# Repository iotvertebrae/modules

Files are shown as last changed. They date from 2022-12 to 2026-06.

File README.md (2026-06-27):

# IoT Vertebrae 

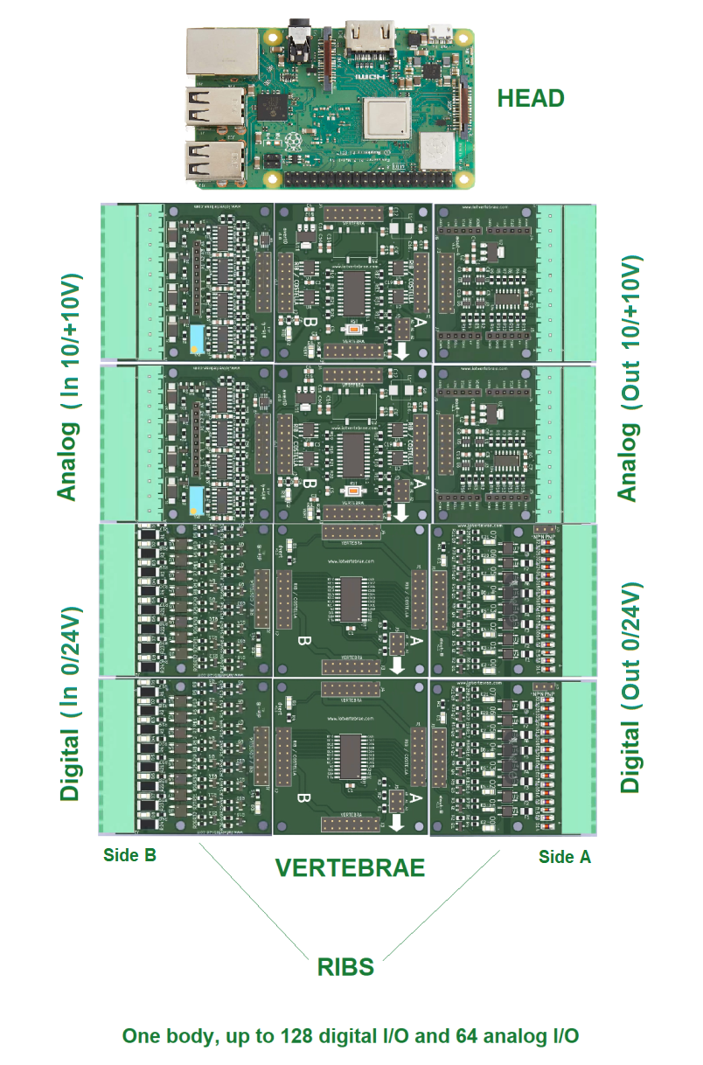
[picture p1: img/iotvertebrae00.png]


The vertebrae bus is an extenxion of the [UEXT](https://www.olimex.com/Products/Modules/UEXT) open bus proposed by Olimex.

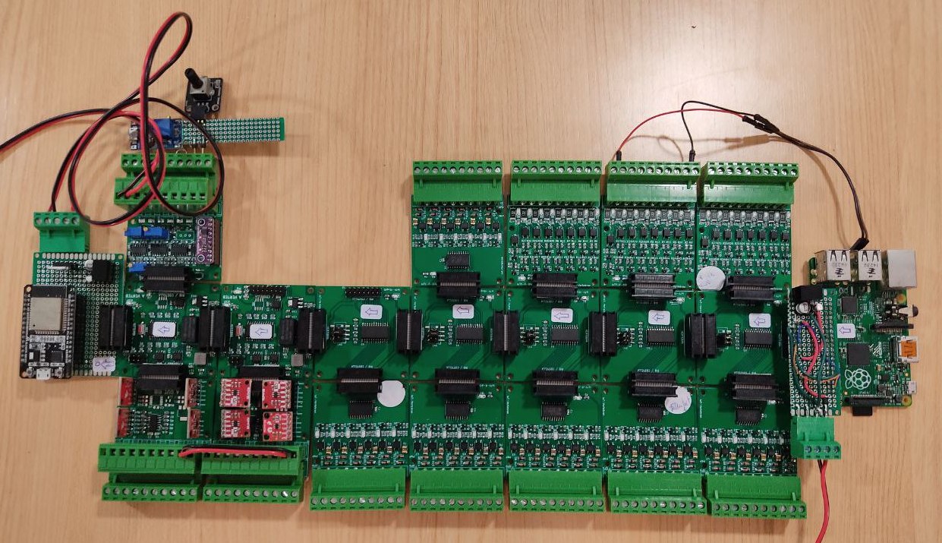
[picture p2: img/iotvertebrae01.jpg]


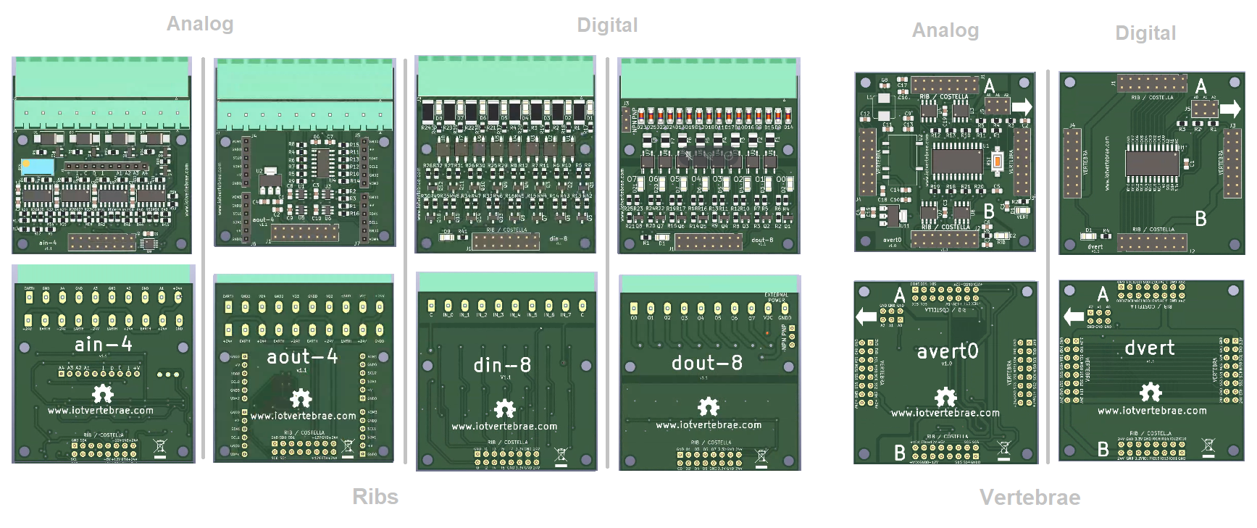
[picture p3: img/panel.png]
Modules


Modules

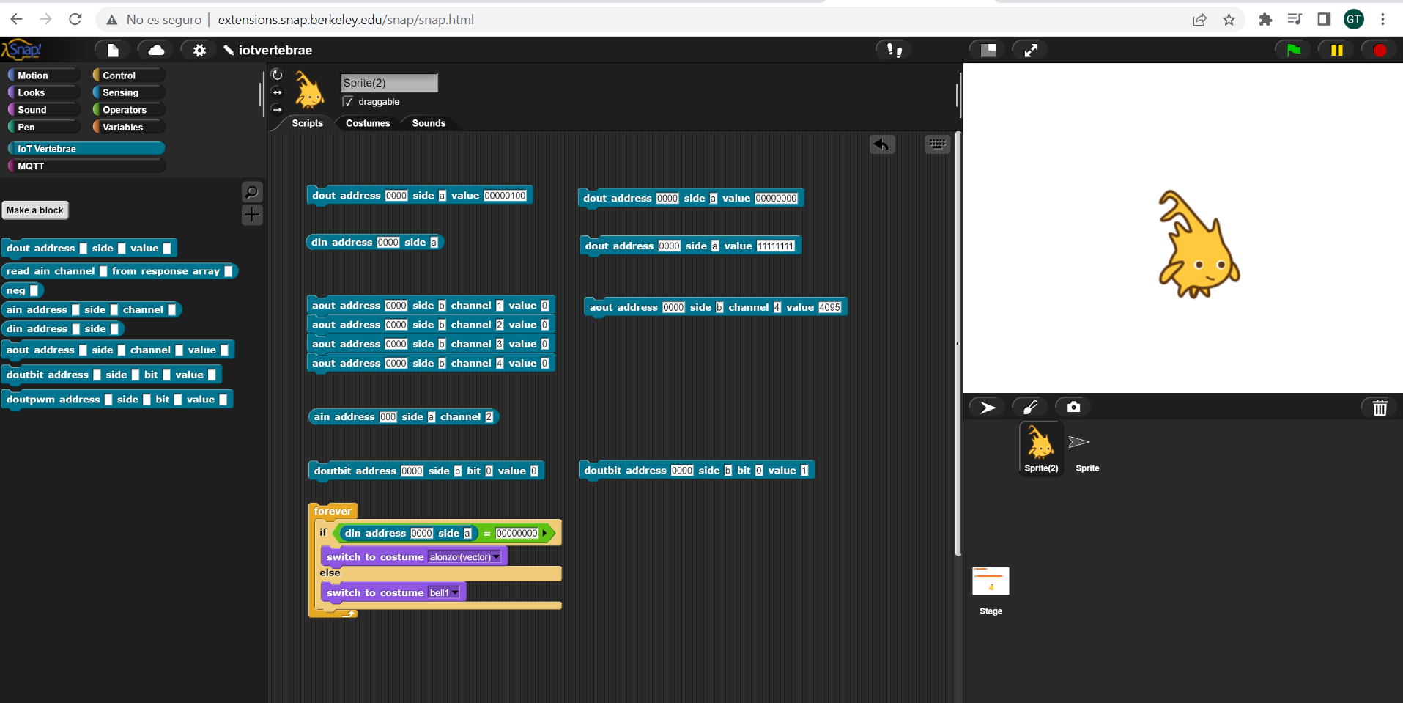
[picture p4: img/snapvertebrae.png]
Software


This project will be provided as open-source hardware.

## [Using IoT Vertebrae (Wiki)](https://www-binefa-com.translate.goog/index.php/IoT-Vertebrae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)

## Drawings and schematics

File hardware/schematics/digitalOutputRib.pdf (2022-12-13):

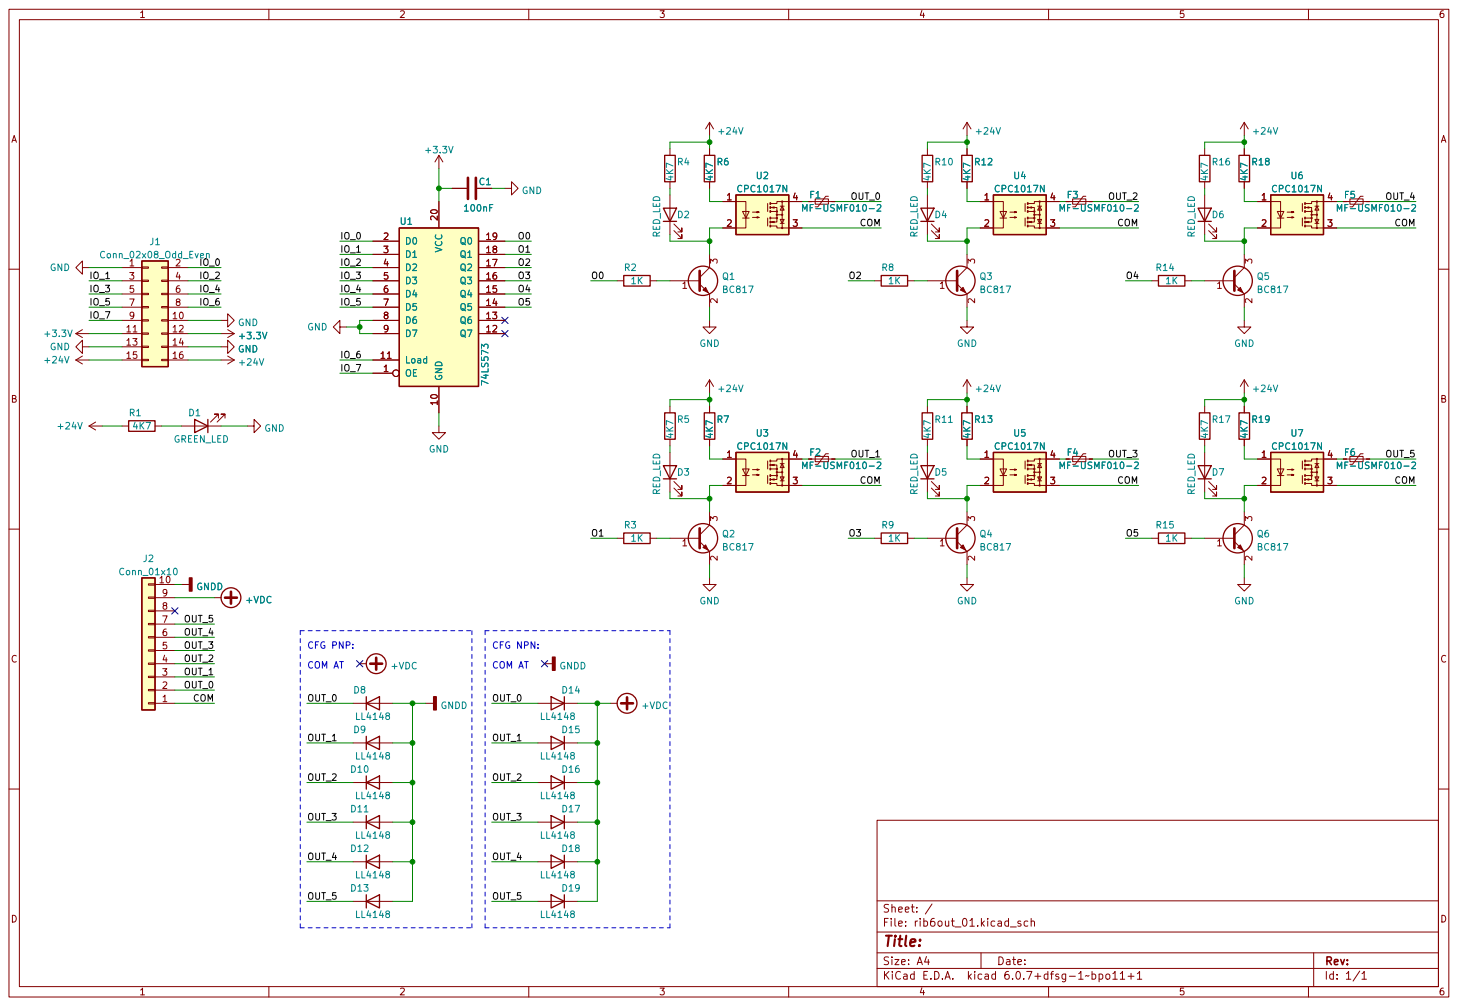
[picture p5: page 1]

2 3 Q6BC817 GND GND GND GND

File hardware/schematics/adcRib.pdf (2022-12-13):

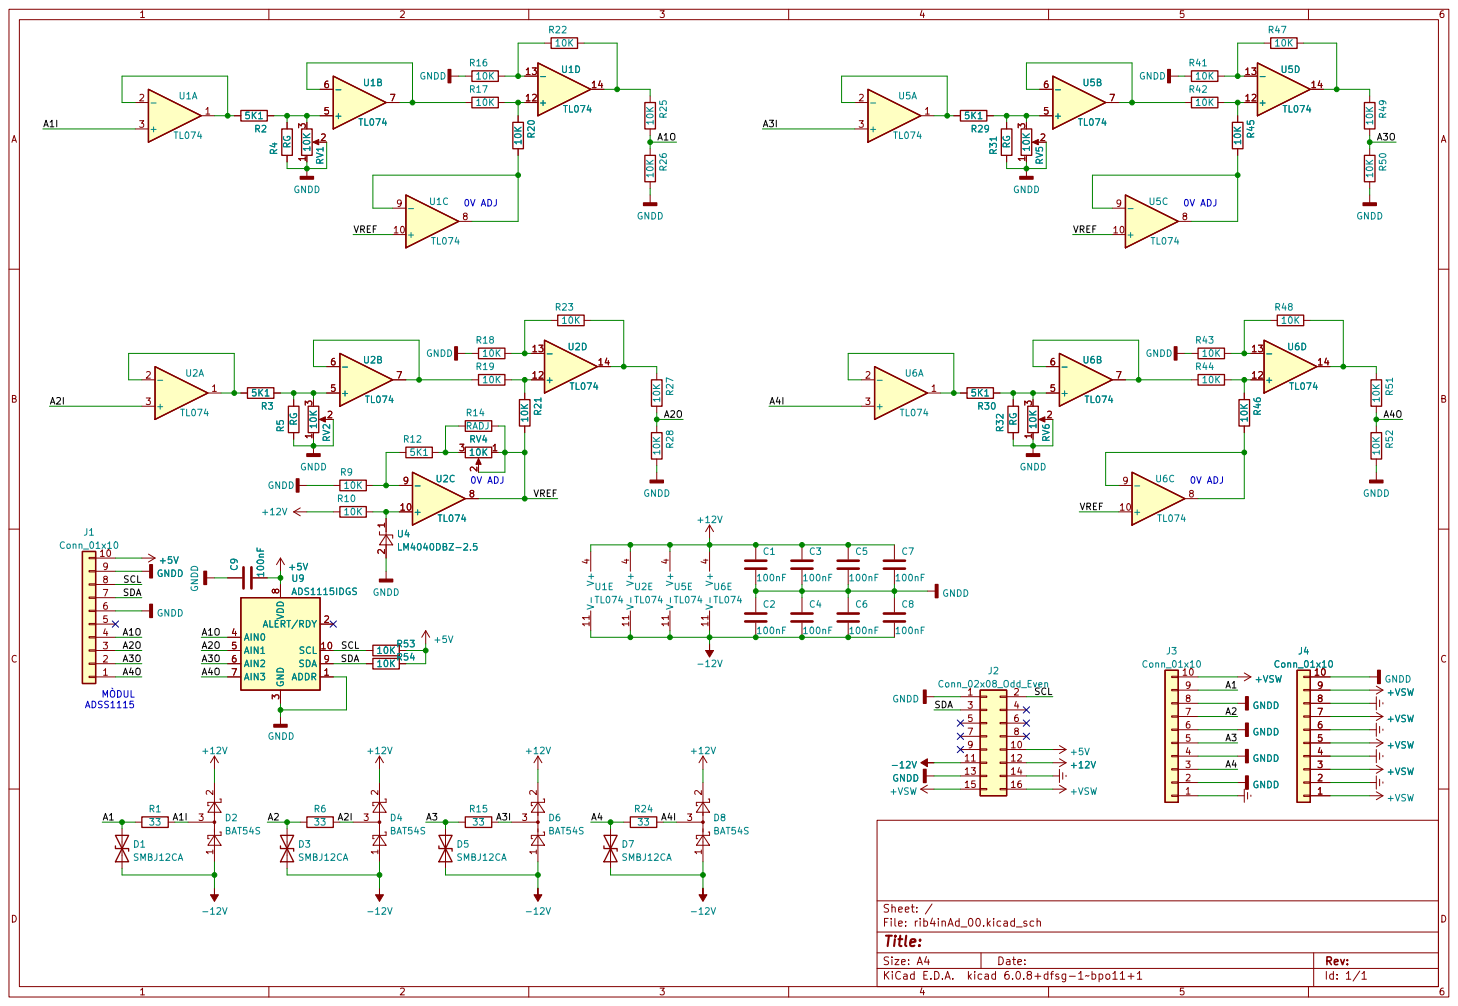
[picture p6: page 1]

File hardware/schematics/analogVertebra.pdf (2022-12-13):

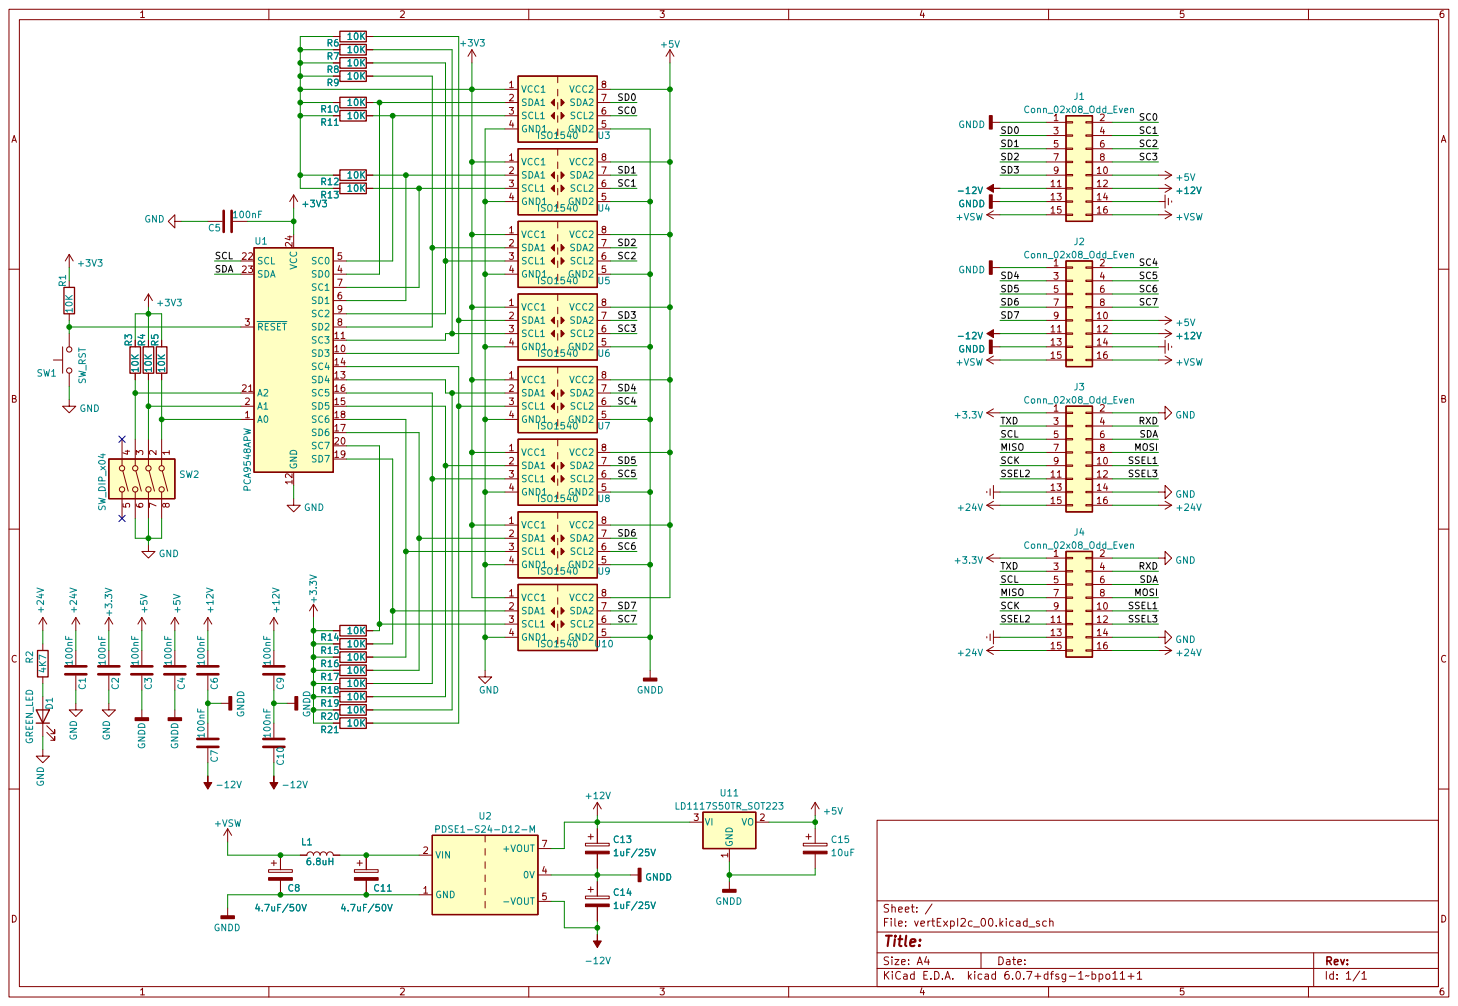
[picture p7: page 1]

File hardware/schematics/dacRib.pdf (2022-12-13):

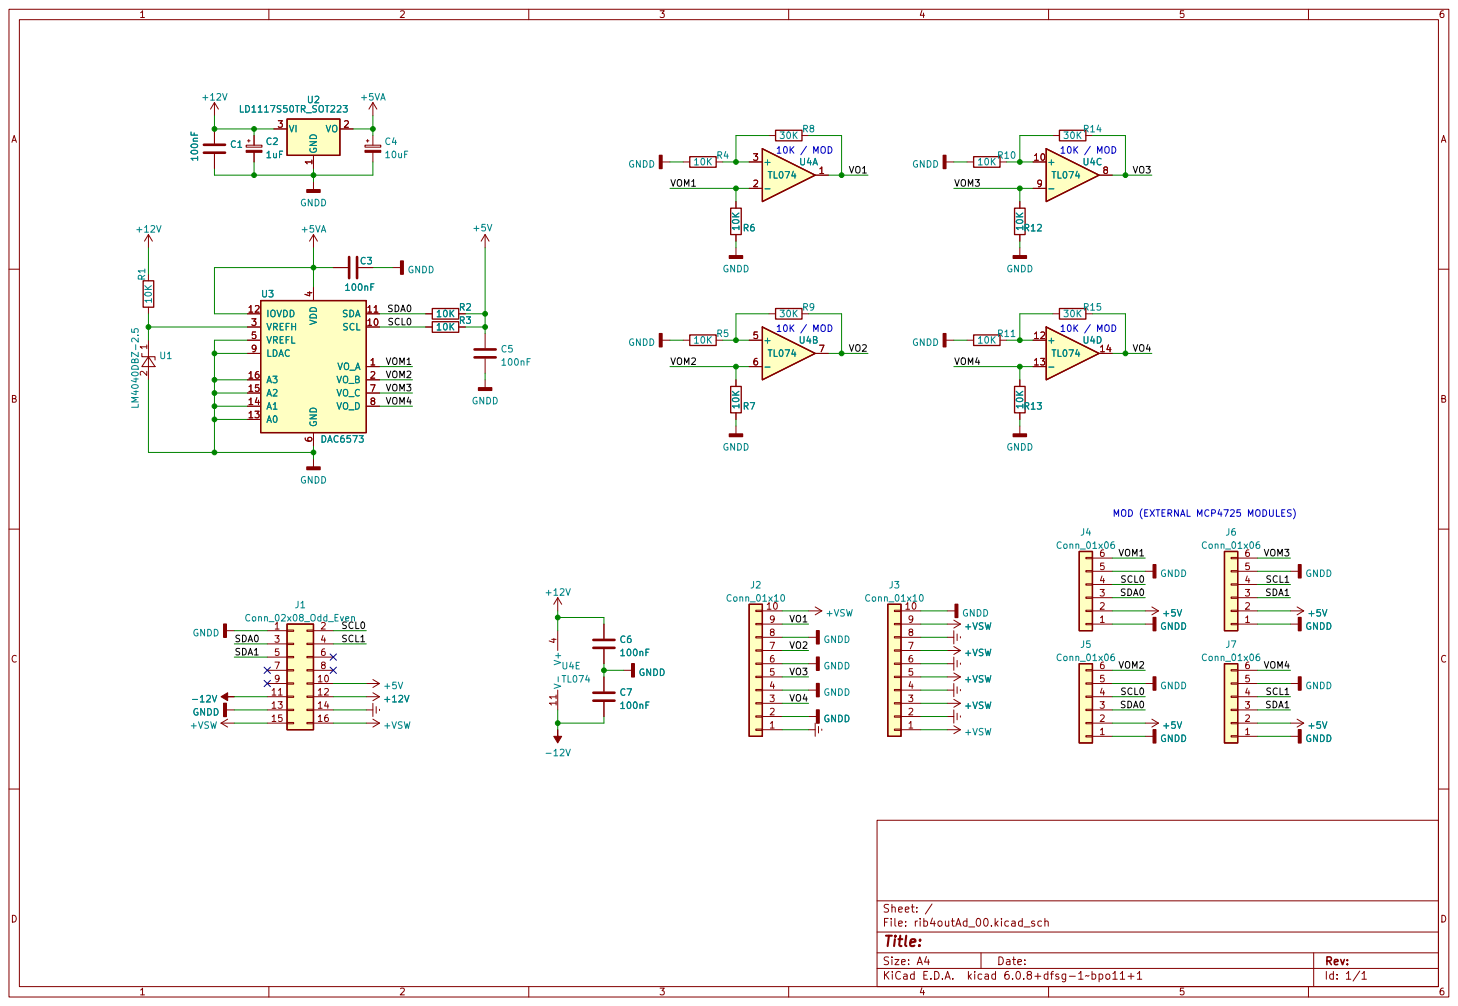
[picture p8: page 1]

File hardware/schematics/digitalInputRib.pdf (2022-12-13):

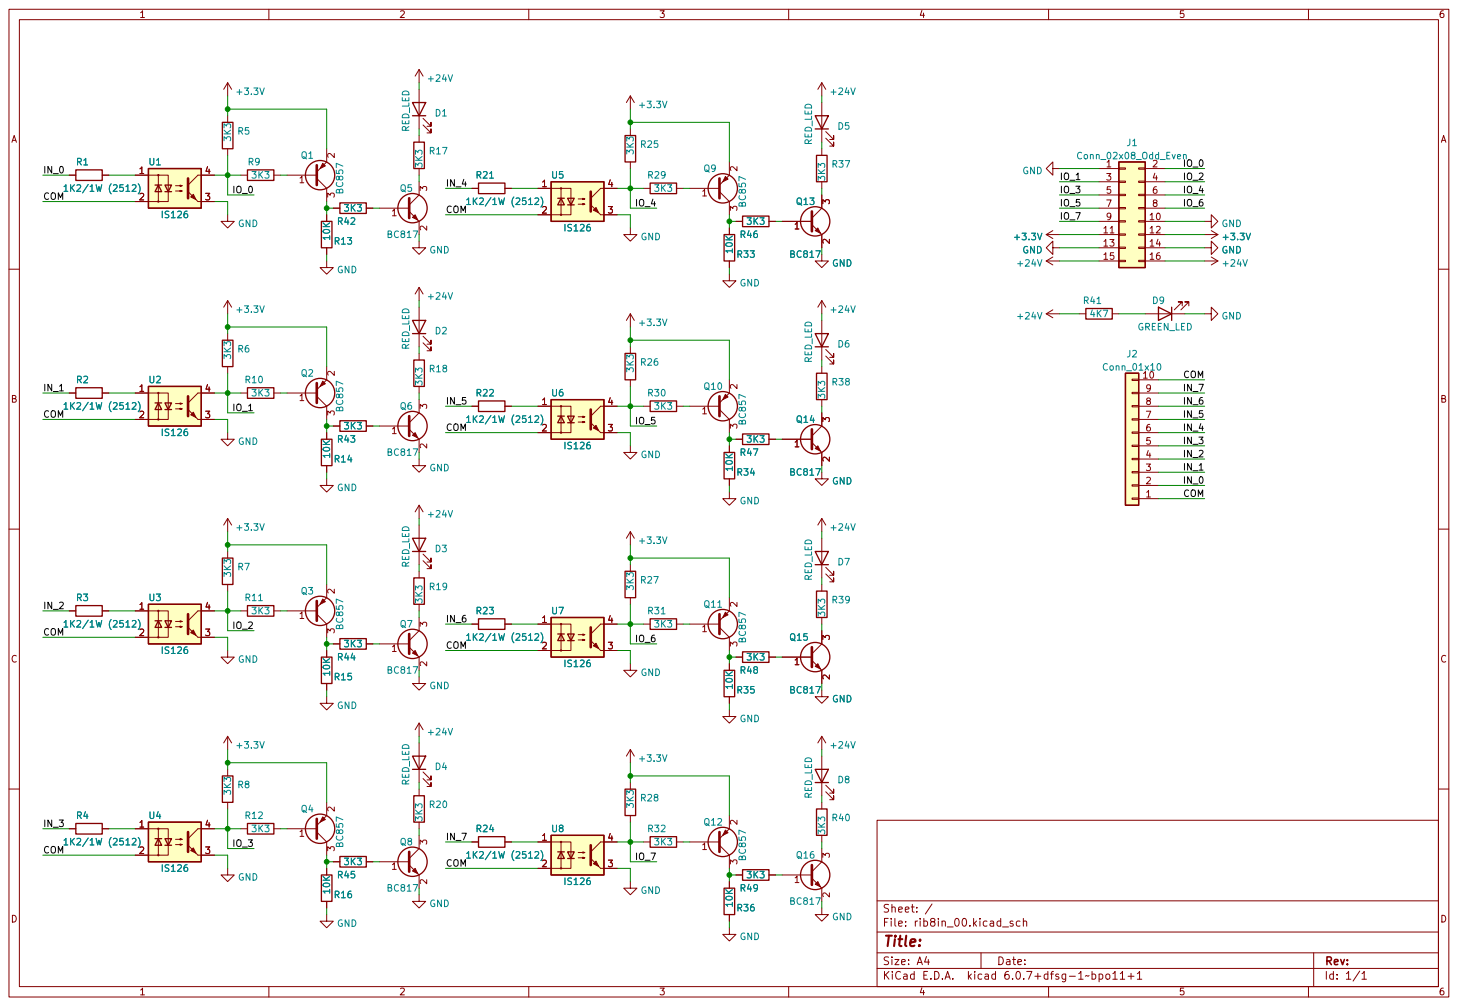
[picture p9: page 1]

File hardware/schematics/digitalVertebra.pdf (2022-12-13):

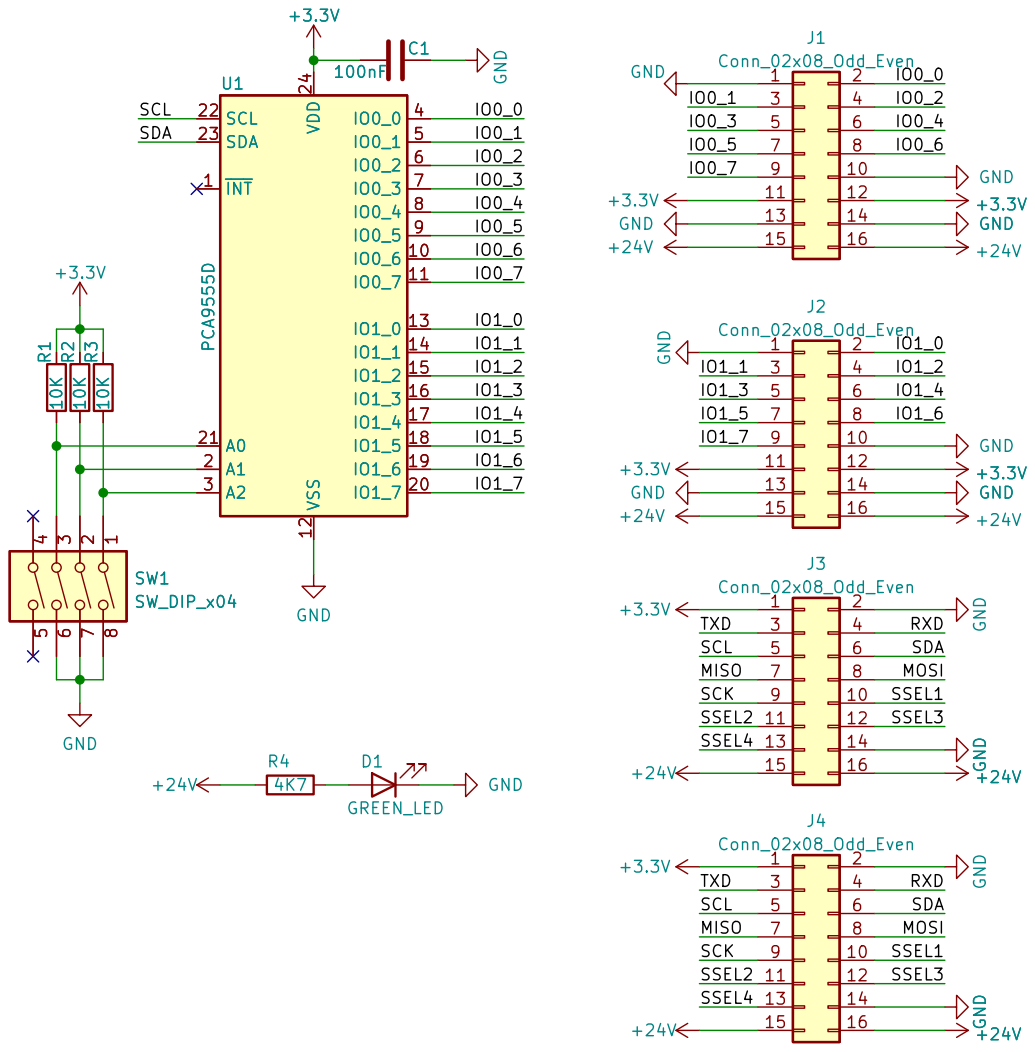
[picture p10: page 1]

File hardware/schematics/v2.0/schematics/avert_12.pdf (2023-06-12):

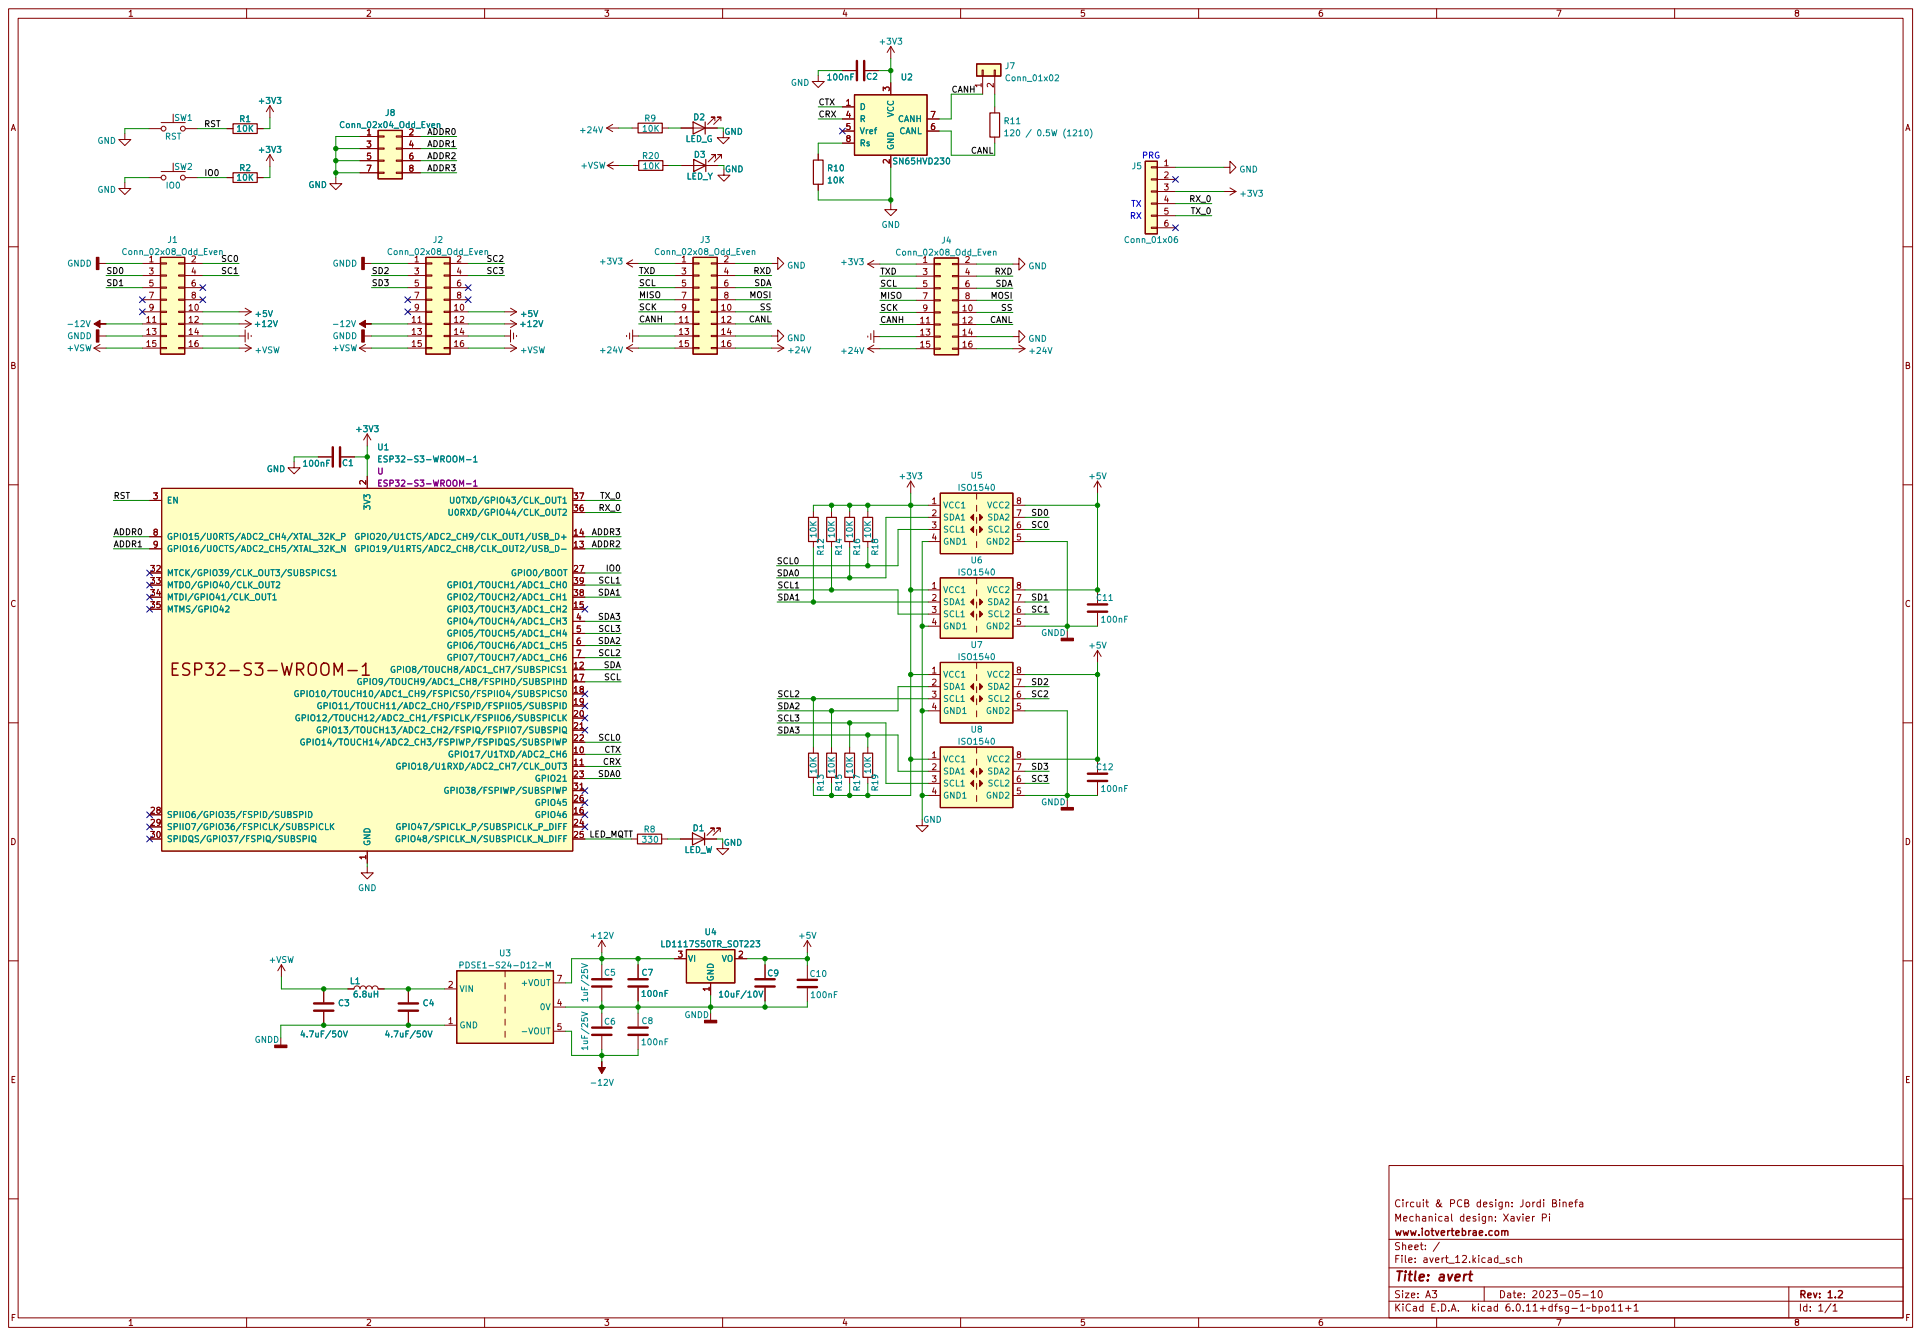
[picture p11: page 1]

2 GPIO12/TOUCH12/ADC2_CH1/FSPICLK/FSPIIO6/SUBSPICLK 20 GPIO13/TOUCH13/ADC2_CH2/FSPIQ/FSPIIO7/SUBSPIQ 21 GPIO14/TOUCH14/ADC2_CH3/FSPIWP/FSPIDQS/SUBSPIWP 22 GPIO21 23 GPIO47/SPICLK_P/SUBSPICLK_P_DIFF 24 GPIO48/SPICLK_N/SUBSPICLK_N_DIFF 25 GPIO45 26 GPIO0/BOOT 27 SPIIO6/GPIO35/FSPID/SUBSPID 28 SPIIO7/GPIO36/FSPICLK/SUBSPICLK 29 EN

1 GPIO17/U1TXD/ADC2_CH6 10 GPIO18/U1RXD/ADC2_CH7/CLK_OUT3 11 GPIO8/TOUCH8/ADC1_CH7/SUBSPICS1 12 GPIO19/U1RTS/ADC2_CH8/CLK_OUT2/USB_D- 13 GPIO20/U1CTS/ADC2_CH9/CLK_OUT1/USB_D+ 14 GPIO3/TOUCH3/ADC1_CH2 15 GPIO46 16 GPIO9/TOUCH9/ADC1_CH8/FSPIHD/SUBSPIHD 17 GPIO10/TOUCH10/ADC1_CH9/FSPICS0/FSPIIO4/SUBSPICS0 18 GPIO11/TOUCH11/ADC2_CH0/FSPID/FSPIIO5/SUBSPID 19 3V3

Id: 1/1 Title: avert File: avert_12.kicad_sch Sheet: / www.iotvertebrae.com

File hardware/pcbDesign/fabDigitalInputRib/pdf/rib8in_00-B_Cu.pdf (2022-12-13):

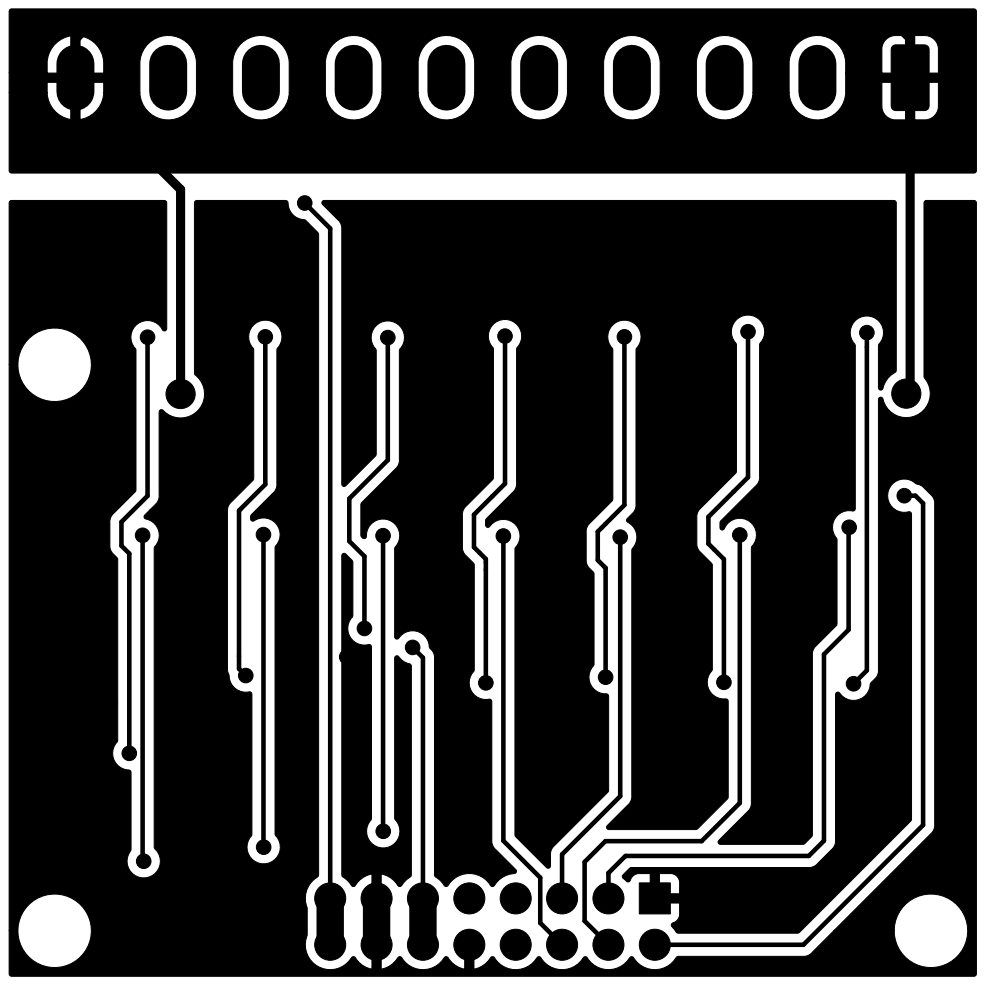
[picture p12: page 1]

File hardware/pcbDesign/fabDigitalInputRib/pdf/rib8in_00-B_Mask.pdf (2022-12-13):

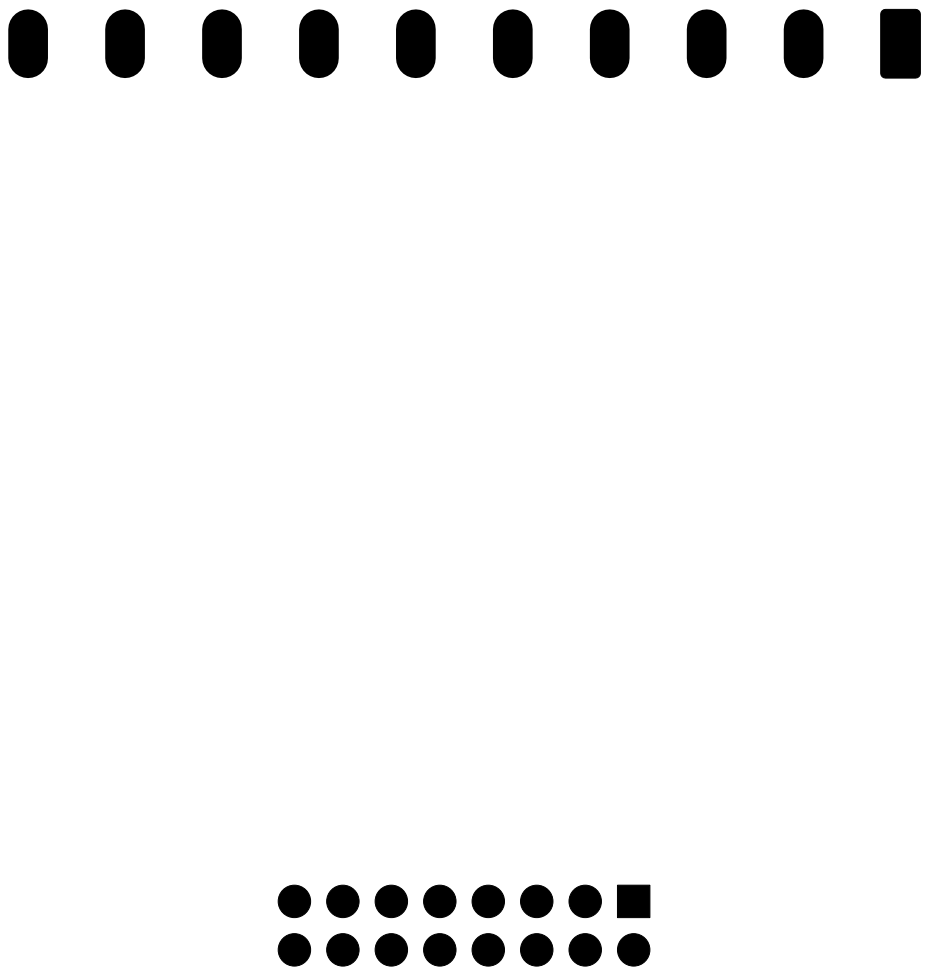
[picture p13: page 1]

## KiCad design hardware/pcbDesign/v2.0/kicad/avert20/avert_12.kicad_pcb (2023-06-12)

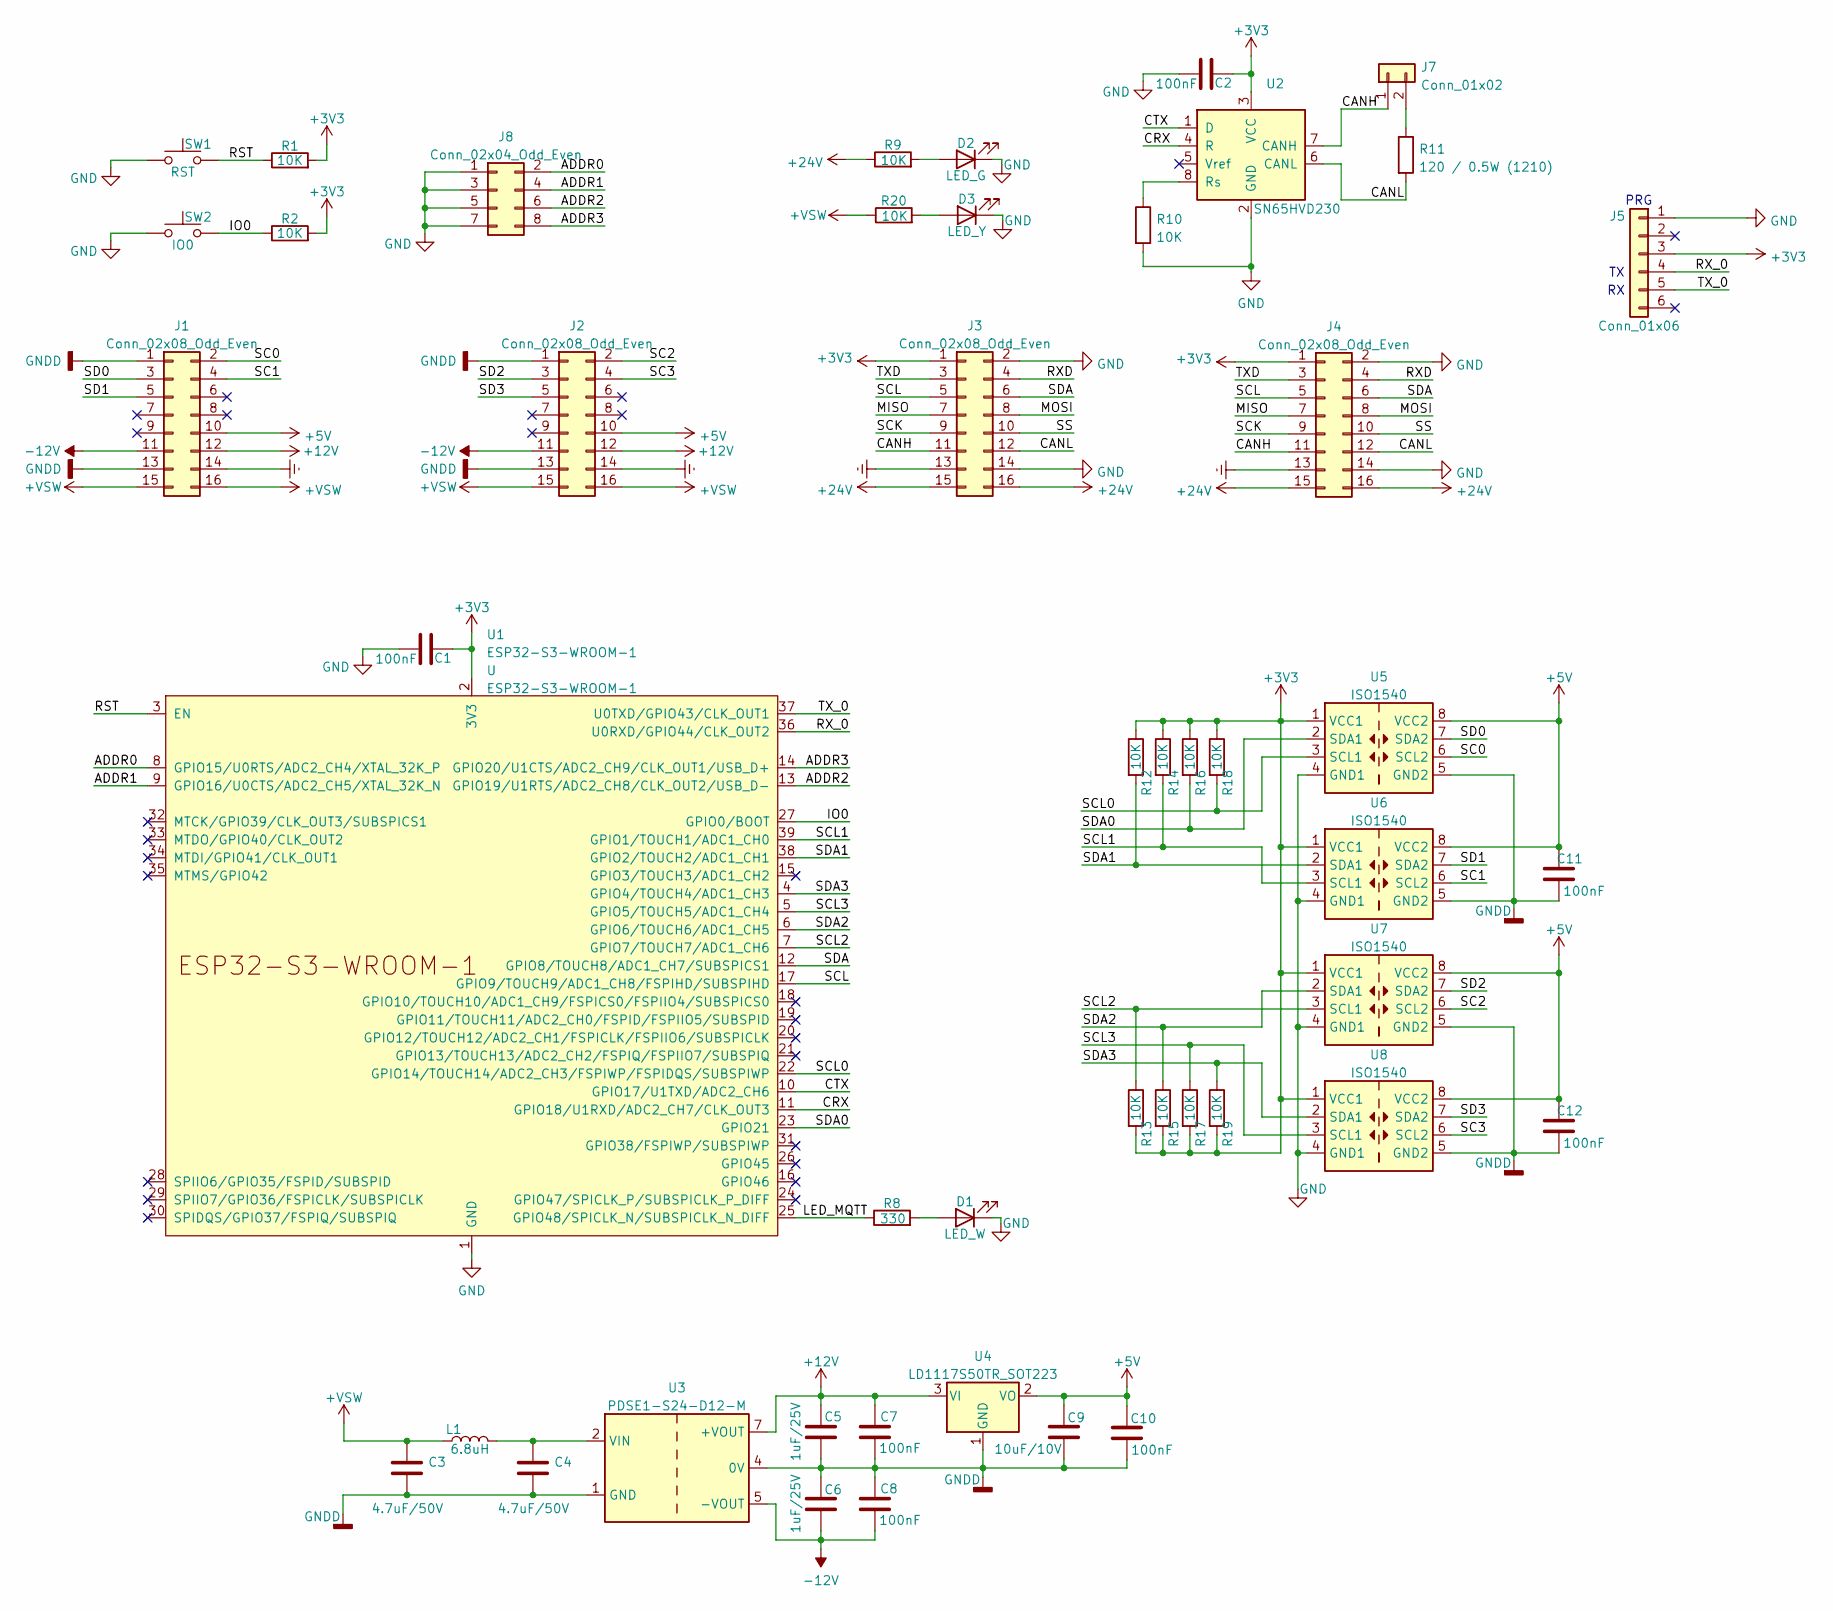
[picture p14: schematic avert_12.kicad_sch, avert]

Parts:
C1, C2, C7, C8, C10, C11, C12: 100nF; C_0805_2012Metric_Pad1.18x1.45mm_HandSolder
C3, C4: 4.7uF/50V; C_0805_2012Metric_Pad1.18x1.45mm_HandSolder
C5, C6: 1uF/25V; C_0805_2012Metric_Pad1.18x1.45mm_HandSolder
C9: 10uF/10V; C_0805_2012Metric_Pad1.18x1.45mm_HandSolder
D1: LED_W; LED_1206_3216Metric_Pad1.42x1.75mm_HandSolder
D2: LED_G; LED_1206_3216Metric_Pad1.42x1.75mm_HandSolder
D3: LED_Y; LED_1206_3216Metric_Pad1.42x1.75mm_HandSolder
J1, J2, J3, J4: Conn_02x08_Odd_Even; IDC-Header_2x08_P2.54mm_Vertical
J5: Conn_01x06; PinSocket_1x06_P2.54mm_Vertical
J7: Conn_01x02; PinHeader_1x02_P2.54mm_Vertical
J8: Conn_02x04_Odd_Even; PinHeader_2x04_P2.54mm_Vertical
L1: 6.8uH; L_Bourns_SRP7028A_7.3x6.6mm
R1, R2, R9, R10, R12, R13, R14, R15, R16, R17, R18, R19, R20: 10K; R_0805_2012Metric_Pad1.20x1.40mm_HandSolder
R8: 330; R_0805_2012Metric_Pad1.20x1.40mm_HandSolder
R11: 120 / 0.5W (1210); R_1210_3225Metric_Pad1.30x2.65mm_HandSolder
SW1: RST; SW_SPST_CK_RS282G05A3
SW2: IO0; SW_SPST_CK_RS282G05A3
U1: ESP32-S3-WROOM-1; ESP32-S3-WROOM-1U
U2: SN65HVD230; SOIC-8_3.9x4.9mm_P1.27mm
U3: PDSE1-S24-D12-M; PDESE1-S24-D12-M
U4: LD1117S50TR_SOT223; SOT-223-3_TabPin2
U5, U6, U7, U8: ISO1540; SOIC-8_3.9x4.9mm_P1.27mm

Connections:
+3V3: C1.2, C2.2, J3.1, J4.1, J5.3, R1.2, R2.2, R12.1, R13.2, R14.1, R15.2, R16.1, R17.2, R18.1, R19.2, U1.2 (3V3), U2.3 (VCC), U5.1 (VCC1), U6.1 (VCC1), U7.1 (VCC1), U8.1 (VCC1)
+5V: C9.1, C10.1, C11.2, C12.2, J1.10, J2.10, U4.2 (VO), U5.8 (VCC2), U6.8 (VCC2), U7.8 (VCC2), U8.8 (VCC2)
+12V: C5.1, C7.1, J1.12, J2.12, U3.7 (+VOUT), U4.3 (VI)
+24V: J3.15, J3.16, J4.15, J4.16, R9.1
+VSW: C3.1, J1.15, J1.16, J2.15, J2.16, L1.1, R20.1
-12V: C6.2, C8.2, J1.11, J2.11, U3.5 (-VOUT)
/ADDR0: J8.2, U1.8 (GPIO15/U0RTS/ADC2_CH4/XTAL_32K_P)
/ADDR1: J8.4, U1.9 (GPIO16/U0CTS/ADC2_CH5/XTAL_32K_N)
/ADDR2: J8.6, U1.13 (GPIO19/U1RTS/ADC2_CH8/CLK_OUT2/USB_D-)
/ADDR3: J8.8, U1.14 (GPIO20/U1CTS/ADC2_CH9/CLK_OUT1/USB_D+)
/CANH: J3.11, J4.11, J7.1, U2.7 (CANH)
/CANL: J3.12, J4.12, R11.2, U2.6 (CANL)
/CRX: U1.11 (GPIO18/U1RXD/ADC2_CH7/CLK_OUT3), U2.4 (R)
/CTX: U1.10 (GPIO17/U1TXD/ADC2_CH6), U2.1 (D)
/IO0: R2.1, SW2.2, U1.27 (GPIO0/BOOT)
/LED_MQTT: R8.1, U1.25 (GPIO48/SPICLK_N/SUBSPICLK_N_DIFF)
/MISO: J3.7, J4.7
/MOSI: J3.8, J4.8
/RST: R1.1, SW1.2, U1.3 (EN)
/RXD: J3.4, J4.4
/RX_0: J5.4, U1.36 (U0RXD/GPIO44/CLK_OUT2)
/SC0: J1.2, U5.6 (SCL2)
/SC1: J1.4, U6.6 (SCL2)
/SC2: J2.2, U7.6 (SCL2)
/SC3: J2.4, U8.6 (SCL2)
/SCK: J3.9, J4.9
/SCL: J3.5, J4.5, U1.17 (GPIO9/TOUCH9/ADC1_CH8/FSPIHD/SUBSPIHD)
/SCL0: R18.2, U1.22 (GPIO14/TOUCH14/ADC2_CH3/FSPIWP/FSPIDQS/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), U5.3 (SCL1)
/SCL1: R14.2, U1.39 (GPIO1/TOUCH1/ADC1_CH0), U6.3 (SCL1)
/SCL2: R13.1, U1.7 (GPIO7/TOUCH7/ADC1_CH6), U7.3 (SCL1)
/SCL3: R17.1, U1.5 (GPIO5/TOUCH5/ADC1_CH4), U8.3 (SCL1)
/SD0: J1.3, U5.7 (SDA2)
/SD1: J1.5, U6.7 (SDA2)
/SD2: J2.3, U7.7 (SDA2)
/SD3: J2.5, U8.7 (SDA2)
/SDA: J3.6, J4.6, U1.12 (GPIO8/TOUCH8/ADC1_CH7/SUBSPICS1)
/SDA0: R16.2, U1.23 (GPIO21), U5.2 (SDA1)
/SDA1: R12.2, U1.38 (GPIO2/TOUCH2/ADC1_CH1), U6.2 (SDA1)
/SDA2: R15.1, U1.6 (GPIO6/TOUCH6/ADC1_CH5), U7.2 (SDA1)
/SDA3: R19.1, U1.4 (GPIO4/TOUCH4/ADC1_CH3), U8.2 (SDA1)
/SS: J3.10, J4.10
/TXD: J3.3, J4.3
/TX_0: J5.5, U1.37 (U0TXD/GPIO43/CLK_OUT1)
Earth: J1.14, J2.14, J3.13, J4.13
GND: C1.1, C2.1, D1.1 (K), D2.1 (K), D3.1 (K), J3.2, J3.14, J4.2, J4.14, J5.1, J8.1, J8.3, J8.5, J8.7, R10.2, SW1.1, SW2.1, U1.1 (GND), U1.40 (GND), U1.41 (GND), U2.2 (GND), U5.4 (GND1), U6.4 (GND1), U7.4 (GND1), U8.4 (GND1)
GNDD: C3.2, C4.2, C5.2, C6.1, C7.2, C8.1, C9.2, C10.2, C11.1, C12.1, J1.1, J1.13, J2.1, J2.13, U3.1 (GND), U3.4 (0V), U4.1 (GND), U5.5 (GND2), U6.5 (GND2), U7.5 (GND2), U8.5 (GND2)
unnamed: C4.1, L1.2, U3.2 (VIN)
unnamed: D1.2 (A), R8.2
unnamed: D2.2 (A), R9.2
unnamed: D3.2 (A), R20.2
unnamed: J7.2, R11.1
unnamed: R10.1, U2.8 (Rs)

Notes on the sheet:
PRG

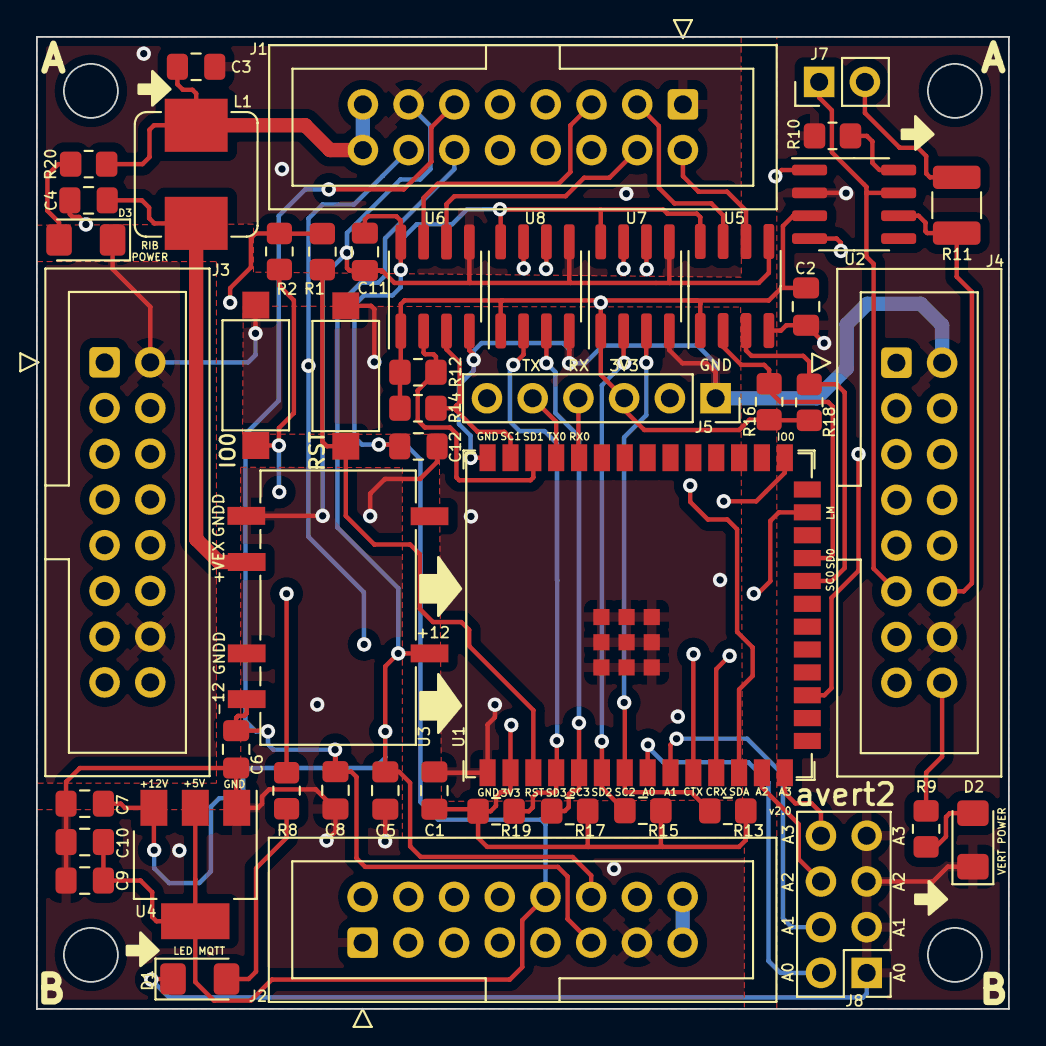
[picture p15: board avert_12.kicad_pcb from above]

Board: 4 copper layers, 54.0 x 54.0 mm, 48 parts (0 on the bottom side), 52 nets.

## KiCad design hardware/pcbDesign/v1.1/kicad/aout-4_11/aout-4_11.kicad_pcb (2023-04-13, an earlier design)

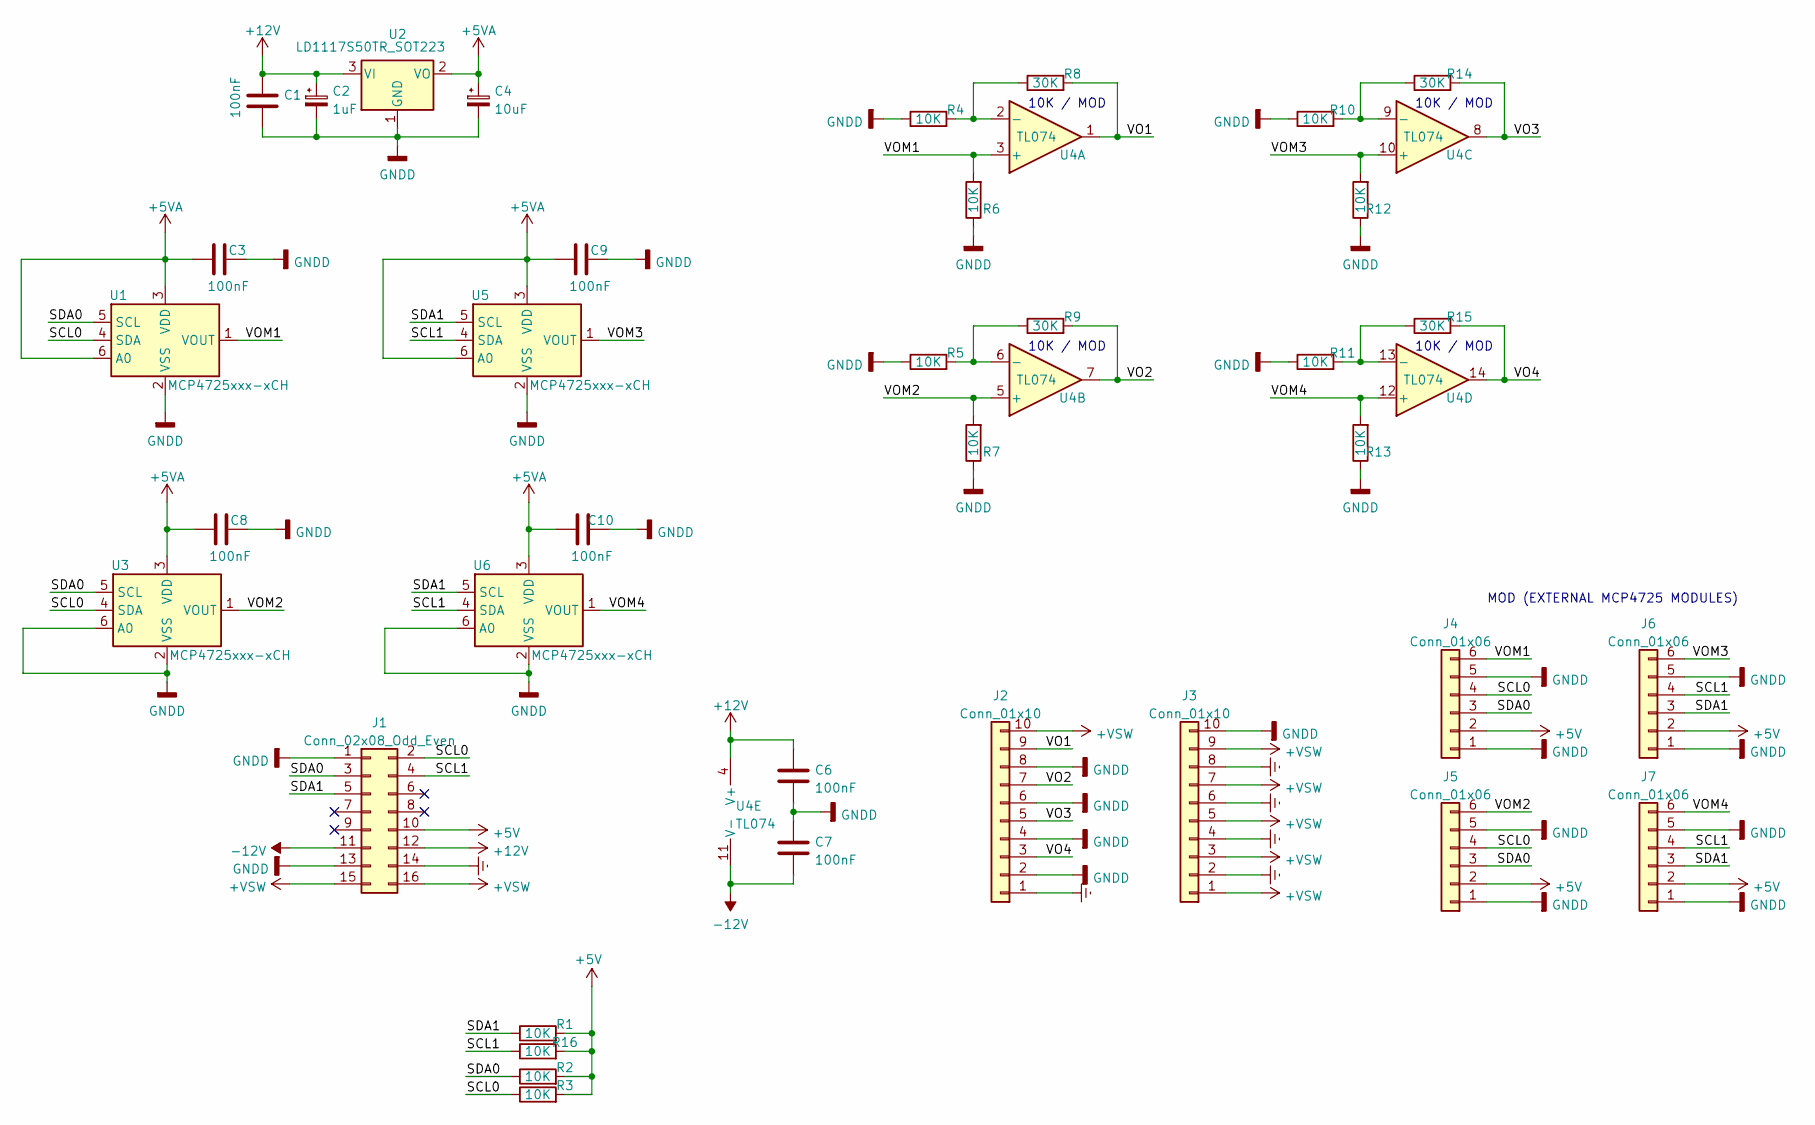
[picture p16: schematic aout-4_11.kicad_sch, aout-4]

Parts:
C1, C3, C6, C7, C8, C9, C10: 100nF; C_0805_2012Metric_Pad1.18x1.45mm_HandSolder
C2: 1uF; C_0805_2012Metric_Pad1.18x1.45mm_HandSolder
C4: 10uF; C_0805_2012Metric_Pad1.18x1.45mm_HandSolder
J1: Conn_02x08_Odd_Even; PinHeader_2x08_P2.54mm_Vertical
J2: Conn_01x10; PhoenixContact_MSTBA_2,5_10-G-5,08_1x10_P5.08mm_Horizontal
J3: Conn_01x10; PhoenixContact_MSTBVA_2,5_10-G-5,08_1x10_P5.08mm_Vertical
J4, J5, J6, J7: Conn_01x06; PinSocket_1x06_P2.54mm_Vertical
R1, R2, R3, R4, R5, R6, R7, R10, R11, R12, R13, R16: 10K; R_0805_2012Metric_Pad1.20x1.40mm_HandSolder
R8, R9, R14, R15: 30K; R_0805_2012Metric_Pad1.20x1.40mm_HandSolder
U1, U3, U5, U6: MCP4725xxx-xCH; SOT-23-6
U2: LD1117S50TR_SOT223; SOT-223-3_TabPin2
U4: TL074; SOIC-14_3.9x8.7mm_P1.27mm

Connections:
+5V: J1.10, J4.2, J5.2, J6.2, J7.2, R1.2, R2.2, R3.2, R16.2
+5VA: C3.1, C4.1, C8.1, C9.1, C10.1, U1.3 (VDD), U1.6 (A0), U2.2 (VO), U3.3 (VDD), U5.3 (VDD), U5.6 (A0), U6.3 (VDD)
+12V: C1.1, C2.1, C6.1, J1.12, U2.3 (VI), U4.4 (V+)
+VSW: J1.15, J1.16, J2.10, J3.1, J3.3, J3.5, J3.7, J3.9
-12V: C7.2, J1.11, U4.11 (V-)
/SCL0: J1.2, J4.4, J5.4, R3.1, U1.4 (SDA), U3.4 (SDA)
/SCL1: J1.4, J6.4, J7.4, R16.1, U5.4 (SDA), U6.4 (SDA)
/SDA0: J1.3, J4.3, J5.3, R2.1, U1.5 (SCL), U3.5 (SCL)
/SDA1: J1.5, J6.3, J7.3, R1.1, U5.5 (SCL), U6.5 (SCL)
/VO1: J2.9, R8.2, U4.1
/VO2: J2.7, R9.2, U4.7
/VO3: J2.5, R14.2, U4.8
/VO4: J2.3, R15.2, U4.14
/VOM1: J4.6, R6.2, U1.1 (VOUT), U4.3 (+)
/VOM2: J5.6, R7.2, U3.1 (VOUT), U4.5 (+)
/VOM3: J6.6, R12.2, U4.10 (+), U5.1 (VOUT)
/VOM4: J7.6, R13.2, U4.12 (+), U6.1 (VOUT)
Earth: J1.14, J2.1, J3.2, J3.4, J3.6, J3.8
GNDD: C1.2, C2.2, C3.2, C4.2, C6.2, C7.1, C8.2, C9.2, C10.2, J1.1, J1.13, J2.2, J2.4, J2.6, J2.8, J3.10, J4.1, J4.5, J5.1, J5.5, J6.1, J6.5, J7.1, J7.5, R4.1, R5.1, R6.1, R7.1, R10.1, R11.1, R12.1, R13.1, U1.2 (VSS), U2.1 (GND), U3.2 (VSS), U3.6 (A0), U5.2 (VSS), U6.2 (VSS), U6.6 (A0)
unnamed: R4.2, R8.1, U4.2 (-)
unnamed: R5.2, R9.1, U4.6 (-)
unnamed: R10.2, R14.1, U4.9 (-)
unnamed: R11.2, R15.1, U4.13 (-)

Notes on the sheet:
10K / MOD
MOD (EXTERNAL MCP4725 MODULES)

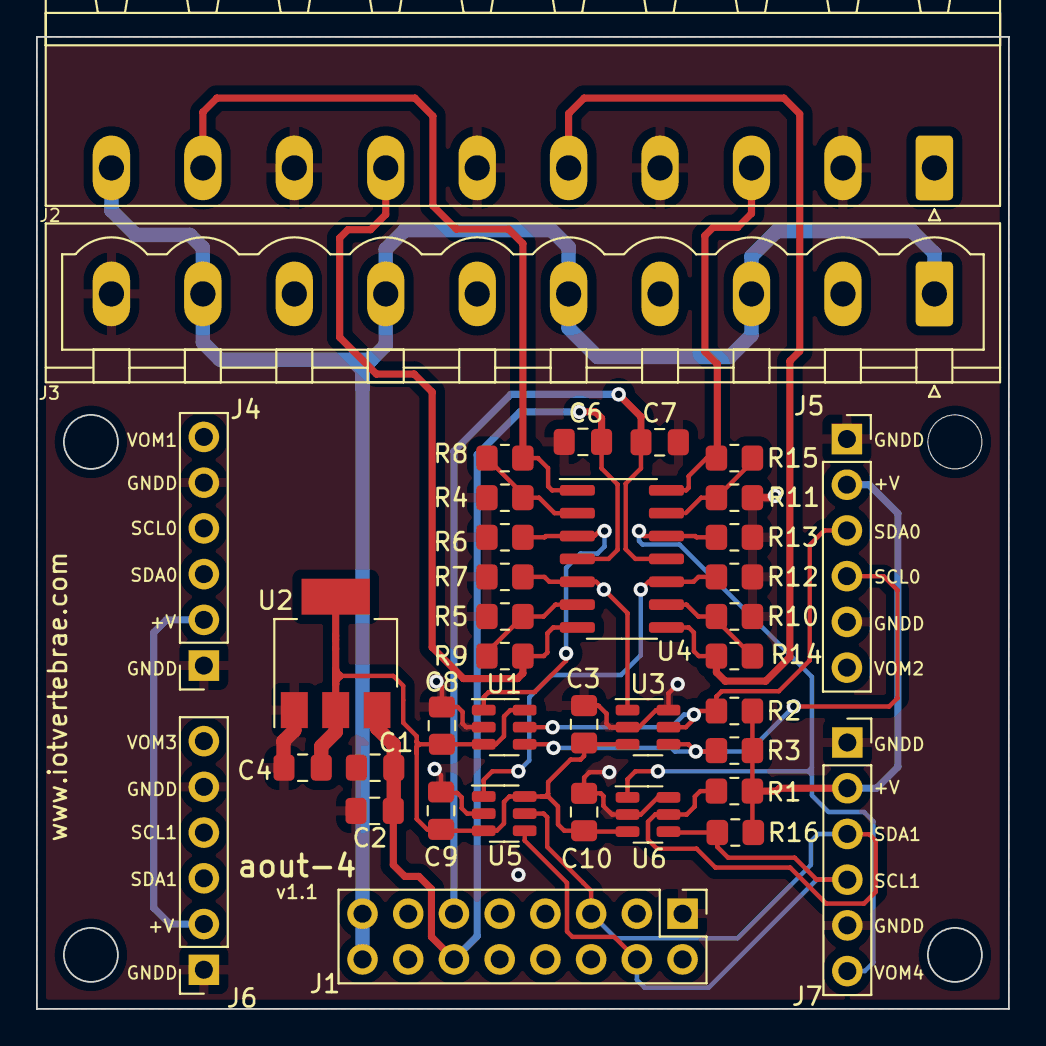
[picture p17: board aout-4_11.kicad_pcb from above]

Board: 4 copper layers, 54.0 x 54.0 mm, 38 parts (0 on the bottom side), 23 nets.

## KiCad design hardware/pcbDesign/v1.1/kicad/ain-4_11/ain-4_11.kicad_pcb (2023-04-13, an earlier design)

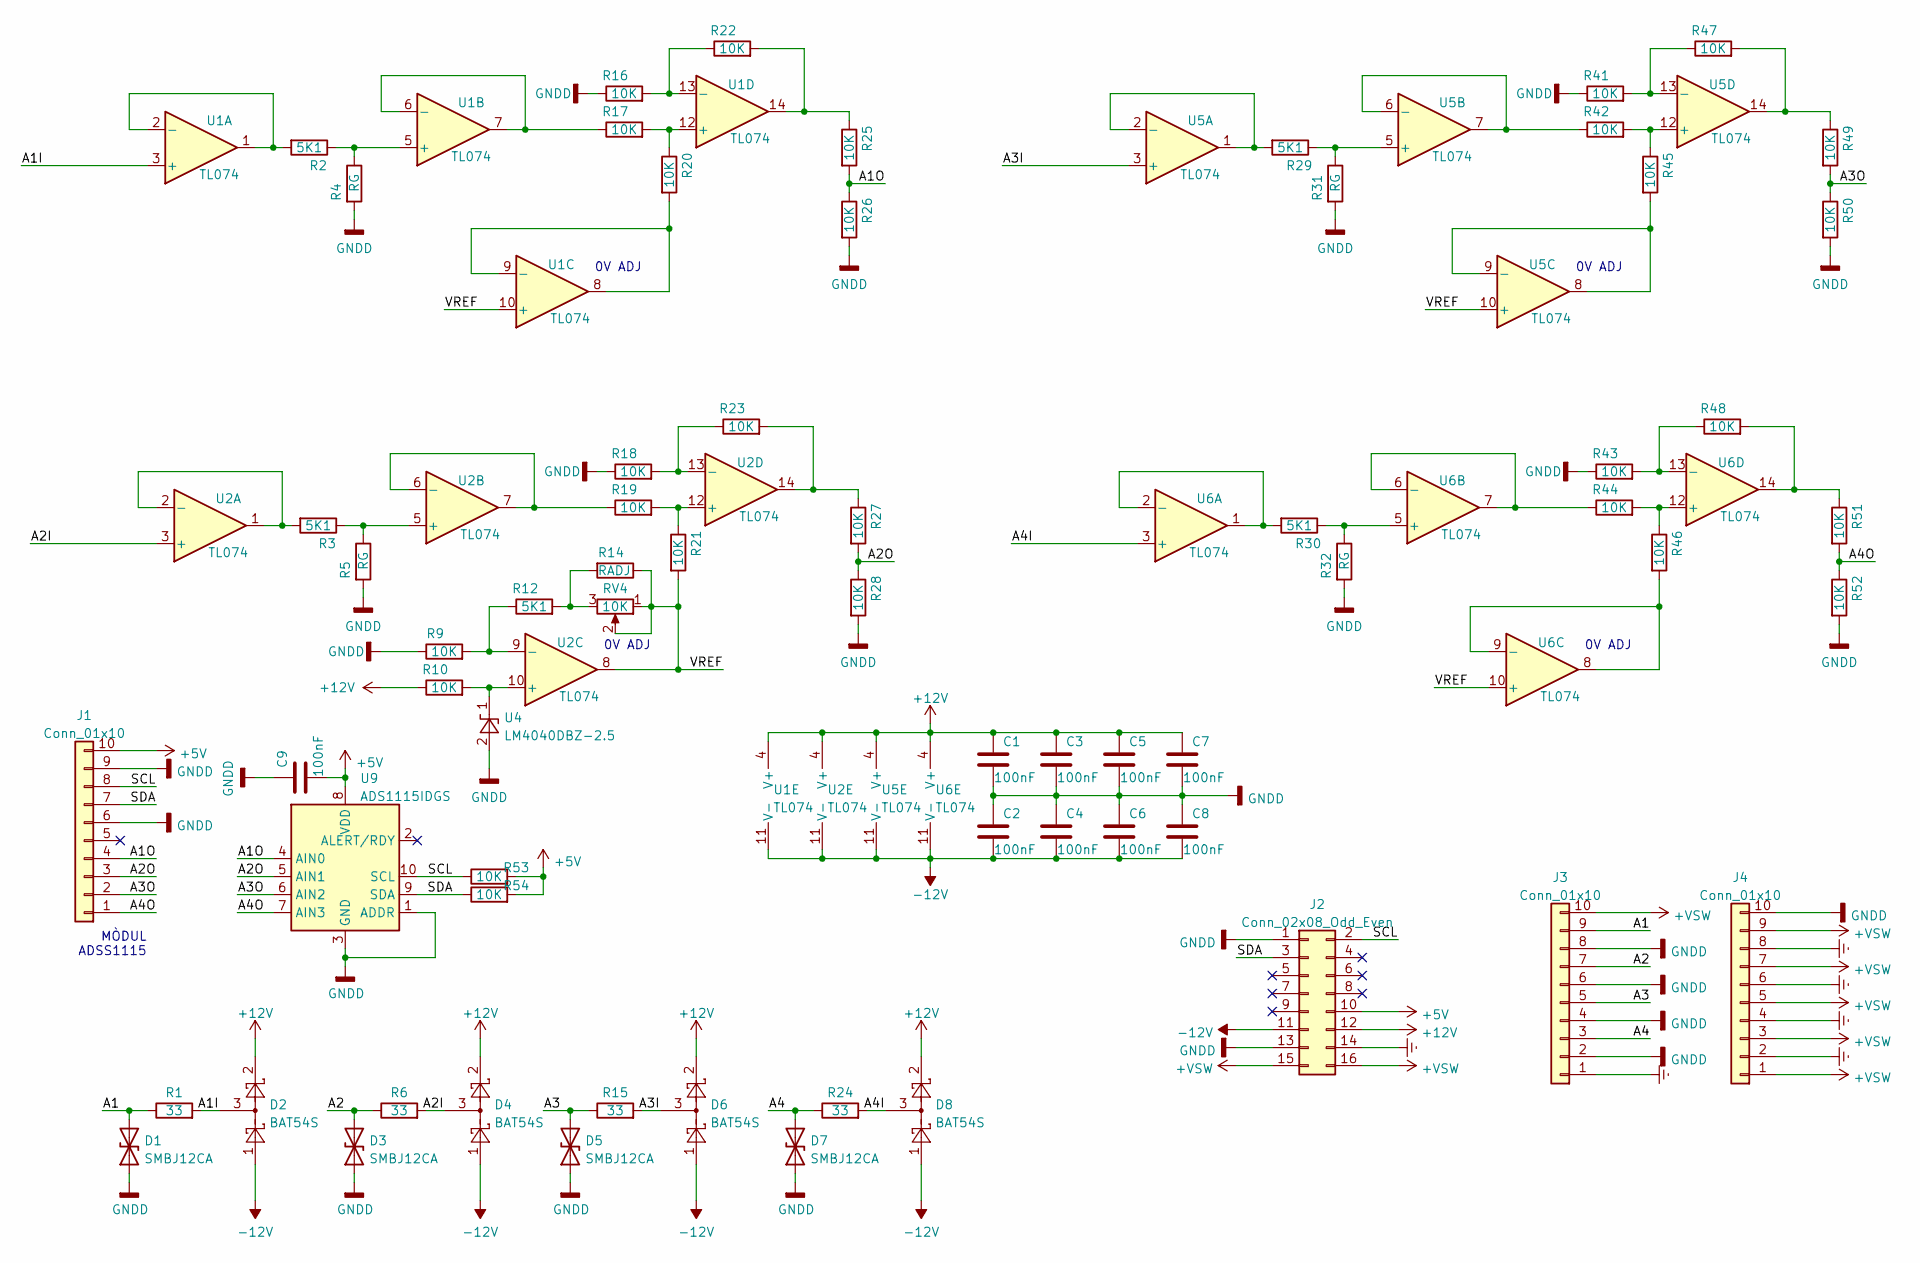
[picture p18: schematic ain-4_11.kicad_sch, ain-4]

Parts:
C1, C2, C3, C4, C5, C6, C7, C8, C9: 100nF; C_0805_2012Metric_Pad1.18x1.45mm_HandSolder
D1, D3, D5, D7: SMBJ12CA; D_SMB_Handsoldering
D2, D4, D6, D8: BAT54S; SOT-23
J1: Conn_01x10; PinSocket_1x10_P2.54mm_Vertical
J2: Conn_02x08_Odd_Even; PinHeader_2x08_P2.54mm_Vertical
J3: Conn_01x10; PhoenixContact_MSTBA_2,5_10-G_1x10_P5.00mm_Horizontal
J4: Conn_01x10; PhoenixContact_MSTBVA_2,5_10-G-5,08_1x10_P5.08mm_Vertical
R1, R6, R15, R24: 33; R_0805_2012Metric_Pad1.20x1.40mm_HandSolder
R2, R3, R12, R29, R30: 5K1; R_0805_2012Metric_Pad1.20x1.40mm_HandSolder
R4, R5, R31, R32: RG; R_0805_2012Metric_Pad1.20x1.40mm_HandSolder
R9, R10, R16, R17, R18, R19, R20, R21, R22, R23, R25, R26, R27, R28, R41, R42, R43, R44, R45, R46, R47, R48, R49, R50, R51, R52, R53, R54: 10K; R_0805_2012Metric_Pad1.20x1.40mm_HandSolder
R14: RADJ; R_0805_2012Metric_Pad1.20x1.40mm_HandSolder
RV4: 10K; Potentiometer_Bourns_3296W_Vertical
U1, U2, U5, U6: TL074; SOIC-14_3.9x8.7mm_P1.27mm
U4: LM4040DBZ-2.5; SOT-23
U9: ADS1115IDGS; TSSOP-10_3x3mm_P0.5mm

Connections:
+5V: C9.2, J1.10, J2.10, R53.2, R54.2, U9.8 (VDD)
+12V: C1.1, C3.1, C5.1, C7.1, D2.2, D4.2, D6.2, D8.2, J2.12, R10.1, U1.4 (V+), U2.4 (V+), U5.4 (V+), U6.4 (V+)
+VSW: J2.15, J2.16, J3.10, J4.1, J4.3, J4.5, J4.7, J4.9
-12V: C2.2, C4.2, C6.2, C8.2, D2.1, D4.1, D6.1, D8.1, J2.11, U1.11 (V-), U2.11 (V-), U5.11 (V-), U6.11 (V-)
/A1: D1.2 (A2), J3.9, R1.1
/A1I: D2.3, R1.2, U1.3 (+)
/A1O: J1.4, R25.2, R26.1, U9.4 (AIN0)
/A2: D3.2 (A2), J3.7, R6.1
/A2I: D4.3, R6.2, U2.3 (+)
/A2O: J1.3, R27.2, R28.1, U9.5 (AIN1)
/A3: D5.2 (A2), J3.5, R15.1
/A3I: D6.3, R15.2, U5.3 (+)
/A3O: J1.2, R49.2, R50.1, U9.6 (AIN2)
/A4: D7.2 (A2), J3.3, R24.1
/A4I: D8.3, R24.2, U6.3 (+)
/A4O: J1.1, R51.2, R52.1, U9.7 (AIN3)
/SCL: J1.8, J2.2, R53.1, U9.10 (SCL)
/SDA: J1.7, J2.3, R54.1, U9.9 (SDA)
/VREF: R14.1, R21.2, RV4.1, RV4.2, U1.10 (+), U2.8, U5.10 (+), U6.10 (+)
Earth: J2.14, J3.1, J4.2, J4.4, J4.6, J4.8
GNDD: C1.2, C2.1, C3.2, C4.1, C5.2, C6.1, C7.2, C8.1, C9.1, D1.1 (A1), D3.1 (A1), D5.1 (A1), D7.1 (A1), J1.6, J1.9, J2.1, J2.13, J3.2, J3.4, J3.6, J3.8, J4.10, R4.2, R5.2, R9.1, R16.1, R18.1, R26.2, R28.2, R31.2, R32.2, R41.1, R43.1, R50.2, R52.2, U4.2 (A), U9.1 (ADDR), U9.3 (GND)
unnamed: R2.1, R4.1, U1.5 (+)
unnamed: R2.2, U1.1, U1.2 (-)
unnamed: R3.1, R5.1, U2.5 (+)
unnamed: R3.2, U2.1, U2.2 (-)
unnamed: R10.2, U2.10 (+), U4.1 (K)
unnamed: R9.2, R12.1, U2.9 (-)
unnamed: R12.2, R14.2, RV4.3
unnamed: R16.2, R22.1, U1.13 (-)
unnamed: R17.1, U1.6 (-), U1.7
unnamed: R17.2, R20.1, U1.12 (+)
unnamed: R18.2, R23.1, U2.13 (-)
unnamed: R19.1, U2.6 (-), U2.7
unnamed: R19.2, R21.1, U2.12 (+)
unnamed: R20.2, U1.8, U1.9 (-)
unnamed: R22.2, R25.1, U1.14
unnamed: R23.2, R27.1, U2.14
unnamed: R29.1, R31.1, U5.5 (+)
unnamed: R29.2, U5.1, U5.2 (-)
unnamed: R30.1, R32.1, U6.5 (+)
unnamed: R30.2, U6.1, U6.2 (-)
unnamed: R41.2, R47.1, U5.13 (-)
unnamed: R42.1, U5.6 (-), U5.7
unnamed: R42.2, R45.1, U5.12 (+)
unnamed: R43.2, R48.1, U6.13 (-)
unnamed: R44.1, U6.6 (-), U6.7
unnamed: R44.2, R46.1, U6.12 (+)
unnamed: R45.2, U5.8, U5.9 (-)
unnamed: R46.2, U6.8, U6.9 (-)
unnamed: R47.2, R49.1, U5.14
unnamed: R48.2, R51.1, U6.14

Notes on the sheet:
0V ADJ
MÒDUL ADSS1115

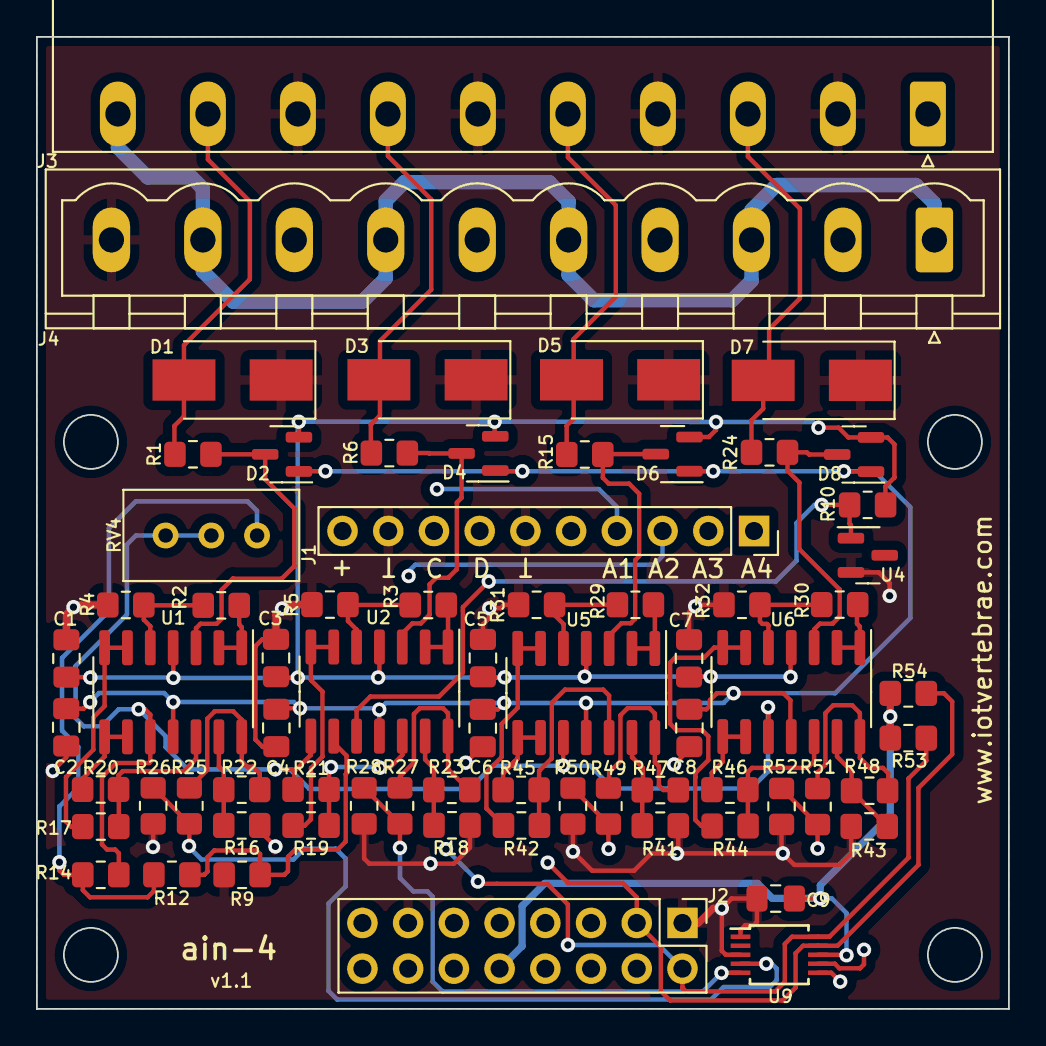
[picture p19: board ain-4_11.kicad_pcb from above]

Board: 4 copper layers, 54.0 x 54.0 mm, 70 parts (0 on the bottom side), 51 nets.

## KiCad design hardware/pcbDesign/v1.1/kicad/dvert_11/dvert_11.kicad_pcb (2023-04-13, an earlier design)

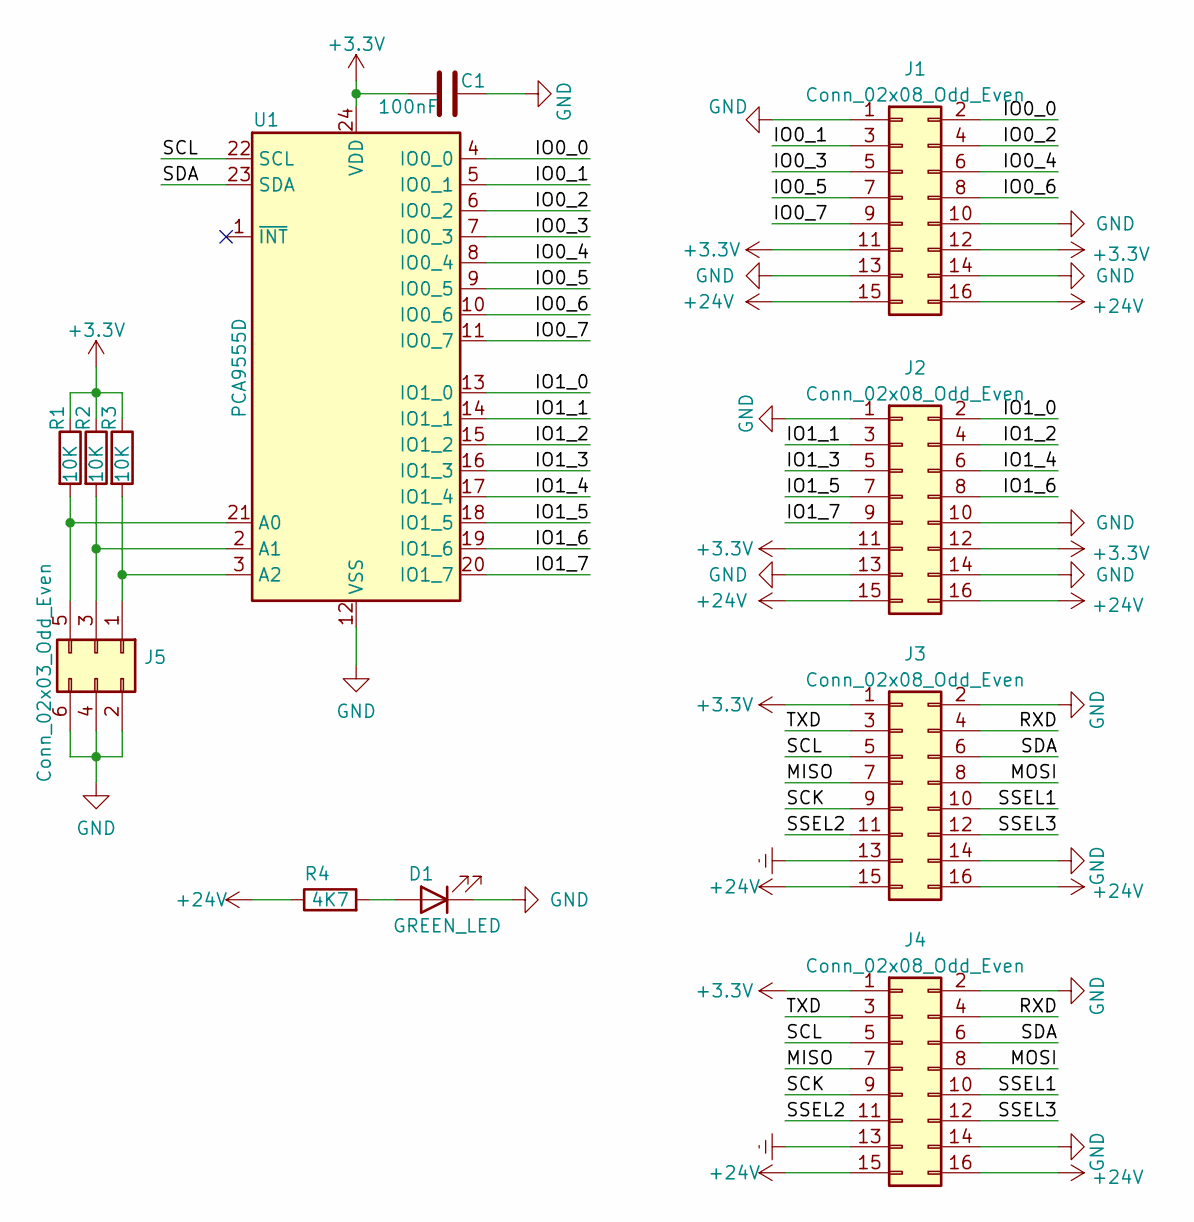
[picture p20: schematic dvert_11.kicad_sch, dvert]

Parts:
C1: 100nF; C_0805_2012Metric_Pad1.18x1.45mm_HandSolder
D1: GREEN_LED; LED_1206_3216Metric_Pad1.42x1.75mm_HandSolder
J1, J2, J3, J4: Conn_02x08_Odd_Even; PinHeader_2x08_P2.54mm_Vertical
J5: Conn_02x03_Odd_Even; PinHeader_2x03_P2.54mm_Vertical
R1, R2, R3: 10K; R_0805_2012Metric_Pad1.20x1.40mm_HandSolder
R4: 4K7; R_0805_2012Metric_Pad1.20x1.40mm_HandSolder
U1: PCA9555D; SOIC-24W_7.5x15.4mm_P1.27mm

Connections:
+3.3V: C1.1, J1.11, J1.12, J2.11, J2.12, J3.1, J4.1, R1.1, R2.1, R3.1, U1.24 (VDD)
+24V: J1.15, J1.16, J2.15, J2.16, J3.15, J3.16, J4.15, J4.16, R4.1
/IO0_0: J1.2, U1.4 (IO0_0)
/IO0_1: J1.3, U1.5 (IO0_1)
/IO0_2: J1.4, U1.6 (IO0_2)
/IO0_3: J1.5, U1.7 (IO0_3)
/IO0_4: J1.6, U1.8 (IO0_4)
/IO0_5: J1.7, U1.9 (IO0_5)
/IO0_6: J1.8, U1.10 (IO0_6)
/IO0_7: J1.9, U1.11 (IO0_7)
/IO1_0: J2.2, U1.13 (IO1_0)
/IO1_1: J2.3, U1.14 (IO1_1)
/IO1_2: J2.4, U1.15 (IO1_2)
/IO1_3: J2.5, U1.16 (IO1_3)
/IO1_4: J2.6, U1.17 (IO1_4)
/IO1_5: J2.7, U1.18 (IO1_5)
/IO1_6: J2.8, U1.19 (IO1_6)
/IO1_7: J2.9, U1.20 (IO1_7)
/MISO: J3.7, J4.7
/MOSI: J3.8, J4.8
/RXD: J3.4, J4.4
/SCK: J3.9, J4.9
/SCL: J3.5, J4.5, U1.22 (SCL)
/SDA: J3.6, J4.6, U1.23 (SDA)
/SSEL1: J3.10, J4.10
/SSEL2: J3.11, J4.11
/SSEL3: J3.12, J4.12
/TXD: J3.3, J4.3
Earth: J3.13, J4.13
GND: C1.2, D1.1 (K), J1.1, J1.10, J1.13, J1.14, J2.1, J2.10, J2.13, J2.14, J3.2, J3.14, J4.2, J4.14, J5.2, J5.4, J5.6, U1.12 (VSS)
unnamed: D1.2 (A), R4.2
unnamed: J5.1, R3.2, U1.3 (A2)
unnamed: J5.3, R2.2, U1.2 (A1)
unnamed: J5.5, R1.2, U1.21 (A0)

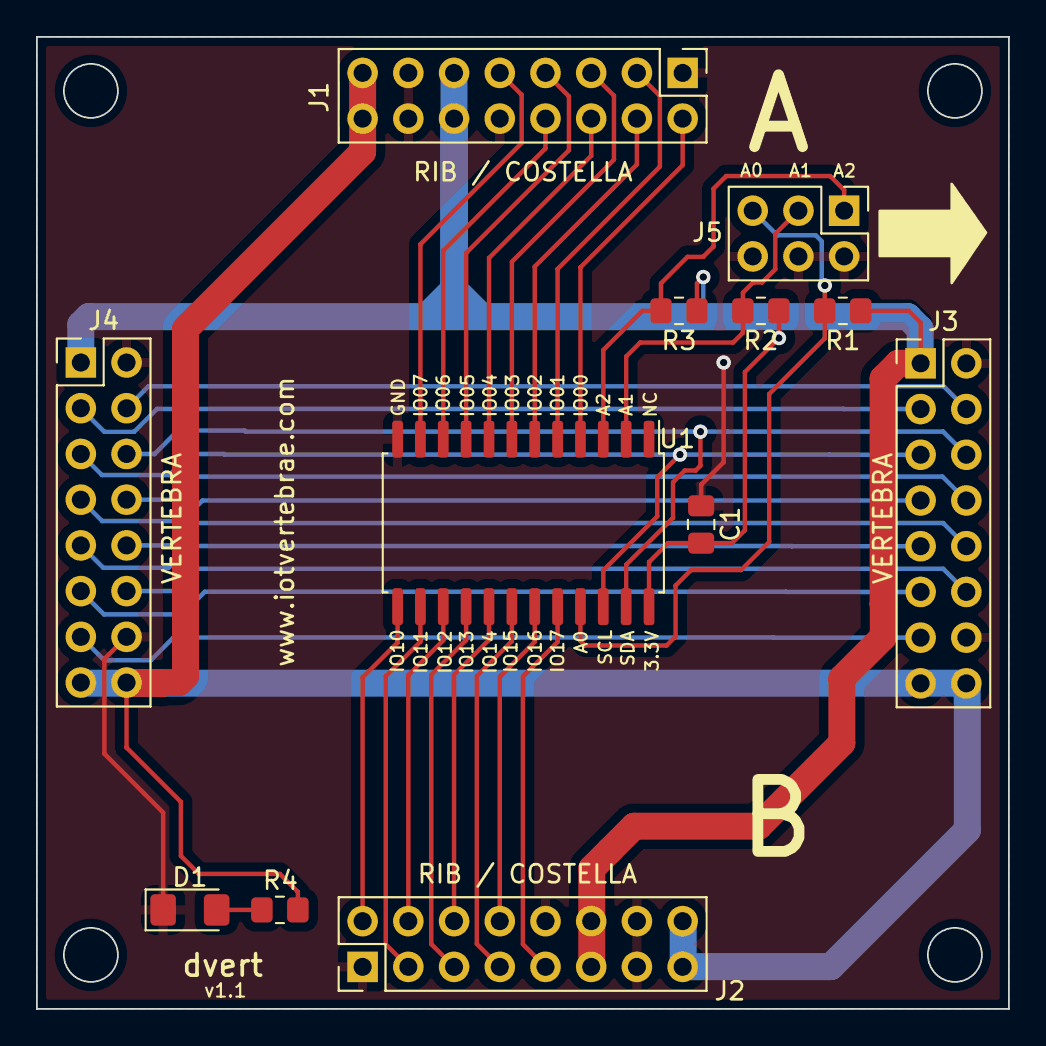
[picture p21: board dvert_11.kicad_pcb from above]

Board: 2 copper layers, 54.0 x 54.0 mm, 12 parts (0 on the bottom side), 34 nets.

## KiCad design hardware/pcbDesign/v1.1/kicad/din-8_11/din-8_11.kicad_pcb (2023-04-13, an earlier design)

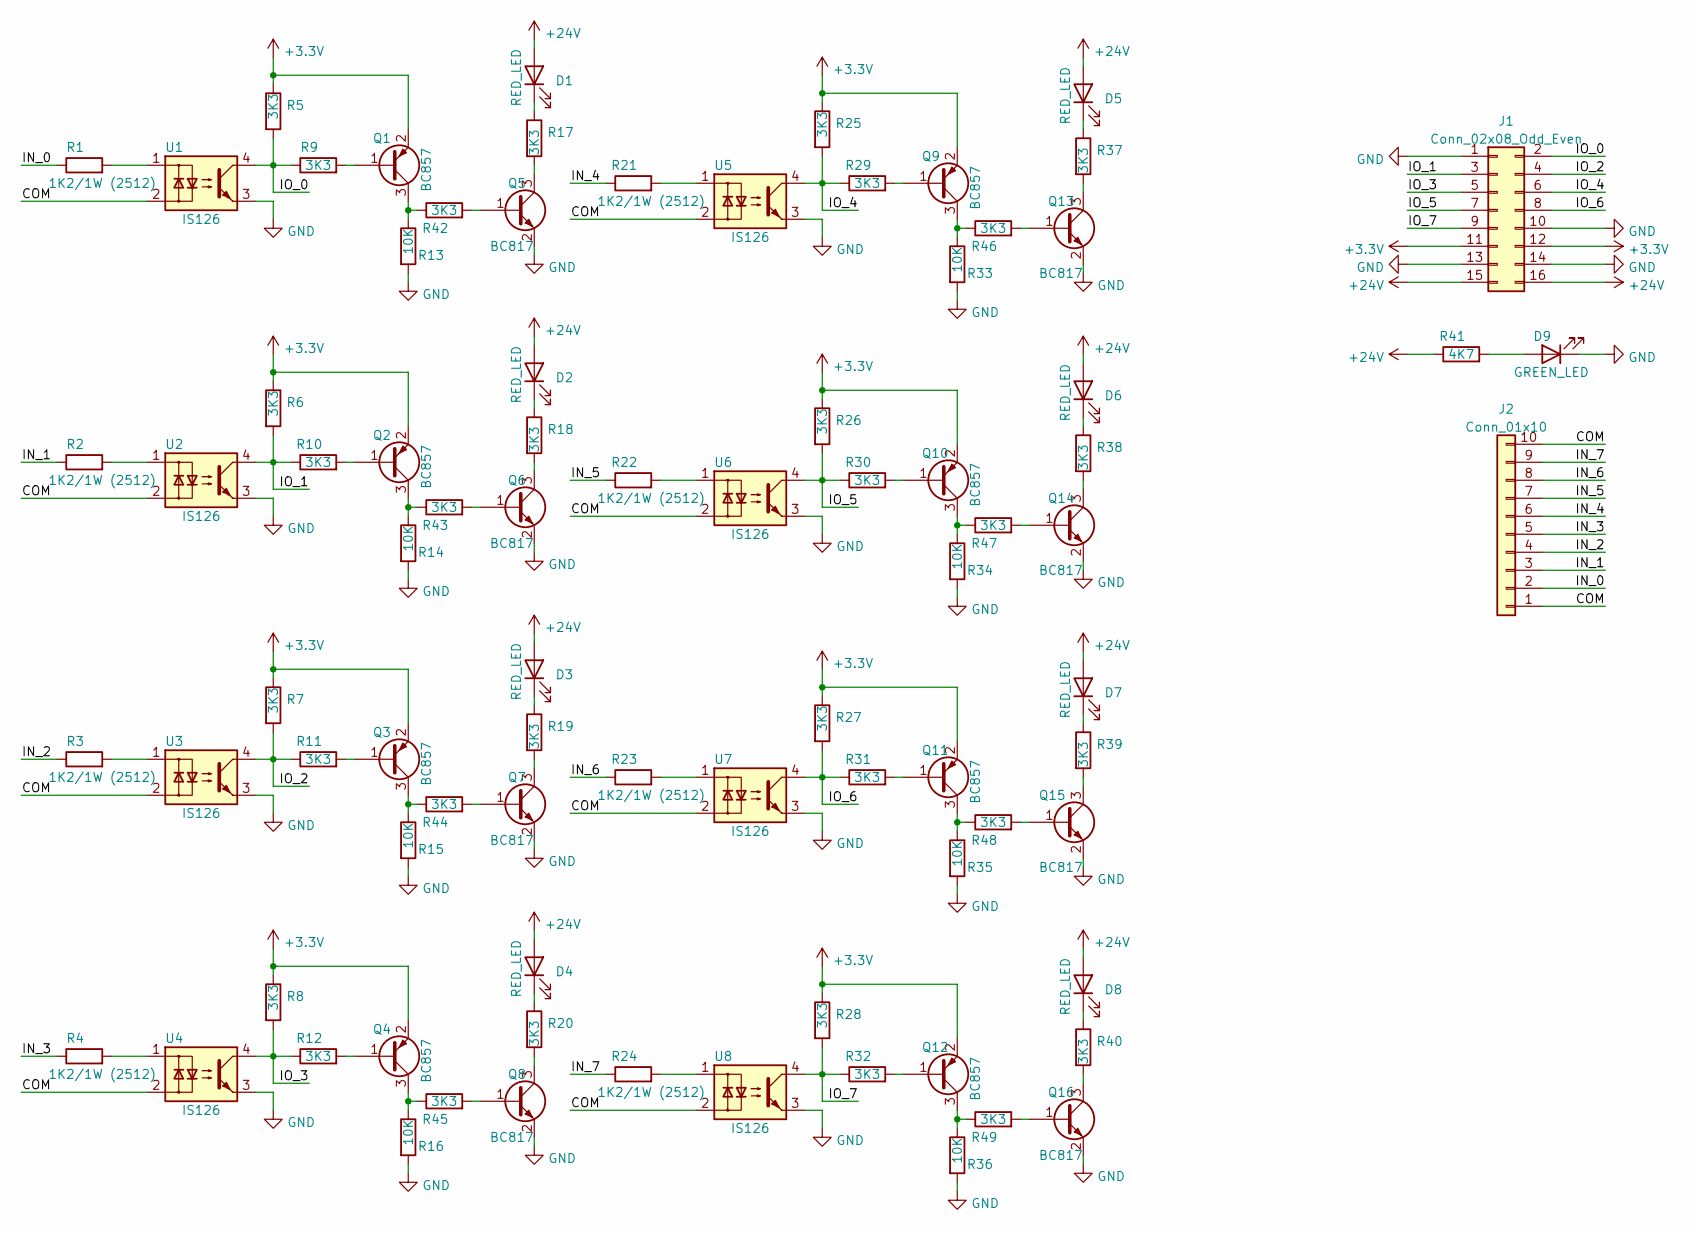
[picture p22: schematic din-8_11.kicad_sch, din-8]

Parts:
D1, D2, D3, D4, D5, D6, D7, D8: RED_LED; LED_1206_3216Metric_Pad1.42x1.75mm_HandSolder
D9: GREEN_LED; LED_1206_3216Metric_Pad1.42x1.75mm_HandSolder
J1: Conn_02x08_Odd_Even; PinHeader_2x08_P2.54mm_Vertical
J2: Conn_01x10; PhoenixContact_MSTBA_2,5_10-G-5,08_1x10_P5.08mm_Horizontal
Q1, Q2, Q3, Q4, Q9, Q10, Q11, Q12: BC857; SOT-23
Q5, Q6, Q7, Q8, Q13, Q14, Q15, Q16: BC817; SOT-23
R1, R2, R3, R4, R21, R22, R23, R24: 1K2/1W (2512); R_2512_6332Metric_Pad1.40x3.35mm_HandSolder
R5, R6, R7, R8, R9, R10, R11, R12, R17, R18, R19, R20, R25, R26, R27, R28, R29, R30, R31, R32, R37, R38, R39, R40, R42, R43, R44, R45, R46, R47, R48, R49: 3K3; R_0805_2012Metric_Pad1.20x1.40mm_HandSolder
R13, R14, R15, R16, R33, R34, R35, R36: 10K; R_0805_2012Metric_Pad1.20x1.40mm_HandSolder
R41: 4K7; R_0805_2012Metric_Pad1.20x1.40mm_HandSolder
U1, U2, U3, U4, U5, U6, U7, U8: IS126; SOIC-4_IS126_4.55x3.7mm_P2.54mm

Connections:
+3.3V: J1.11, J1.12, Q1.2 (E), Q2.2 (E), Q3.2 (E), Q4.2 (E), Q9.2 (E), Q10.2 (E), Q11.2 (E), Q12.2 (E), R5.1, R6.1, R7.1, R8.1, R25.1, R26.1, R27.1, R28.1
+24V: D1.2 (A), D2.2 (A), D3.2 (A), D4.2 (A), D5.2 (A), D6.2 (A), D7.2 (A), D8.2 (A), J1.15, J1.16, R41.1
/COM: J2.1, J2.10, U1.2, U2.2, U3.2, U4.2, U5.2, U6.2, U7.2, U8.2
/IN_0: J2.2, R1.1
/IN_1: J2.3, R2.1
/IN_2: J2.4, R3.1
/IN_3: J2.5, R4.1
/IN_4: J2.6, R21.1
/IN_5: J2.7, R22.1
/IN_6: J2.8, R23.1
/IN_7: J2.9, R24.1
/IO_0: J1.2, R5.2, R9.1, U1.4
/IO_1: J1.3, R6.2, R10.1, U2.4
/IO_2: J1.4, R7.2, R11.1, U3.4
/IO_3: J1.5, R8.2, R12.1, U4.4
/IO_4: J1.6, R25.2, R29.1, U5.4
/IO_5: J1.7, R26.2, R30.1, U6.4
/IO_6: J1.8, R27.2, R31.1, U7.4
/IO_7: J1.9, R28.2, R32.1, U8.4
GND: D9.1 (K), J1.1, J1.10, J1.13, J1.14, Q5.2 (E), Q6.2 (E), Q7.2 (E), Q8.2 (E), Q13.2 (E), Q14.2 (E), Q15.2 (E), Q16.2 (E), R13.2, R14.2, R15.2, R16.2, R33.2, R34.2, R35.2, R36.2, U1.3, U2.3, U3.3, U4.3, U5.3, U6.3, U7.3, U8.3
unnamed: D1.1 (K), R17.1
unnamed: D2.1 (K), R18.1
unnamed: D3.1 (K), R19.1
unnamed: D4.1 (K), R20.1
unnamed: D5.1 (K), R37.1
unnamed: D6.1 (K), R38.1
unnamed: D7.1 (K), R39.1
unnamed: D8.1 (K), R40.1
unnamed: D9.2 (A), R41.2
unnamed: Q1.1 (B), R9.2
unnamed: Q1.3 (C), R13.1, R42.1
unnamed: Q2.1 (B), R10.2
unnamed: Q2.3 (C), R14.1, R43.1
unnamed: Q3.1 (B), R11.2
unnamed: Q3.3 (C), R15.1, R44.1
unnamed: Q4.1 (B), R12.2
unnamed: Q4.3 (C), R16.1, R45.1
unnamed: Q5.1 (B), R42.2
unnamed: Q5.3 (C), R17.2
unnamed: Q6.1 (B), R43.2
unnamed: Q6.3 (C), R18.2
unnamed: Q7.1 (B), R44.2
unnamed: Q7.3 (C), R19.2
unnamed: Q8.1 (B), R45.2
unnamed: Q8.3 (C), R20.2
unnamed: Q9.1 (B), R29.2
unnamed: Q9.3 (C), R33.1, R46.1
unnamed: Q10.1 (B), R30.2
unnamed: Q10.3 (C), R34.1, R47.1
unnamed: Q11.1 (B), R31.2
unnamed: Q11.3 (C), R35.1, R48.1
unnamed: Q12.1 (B), R32.2
unnamed: Q12.3 (C), R36.1, R49.1
unnamed: Q13.1 (B), R46.2
unnamed: Q13.3 (C), R37.2
unnamed: Q14.1 (B), R47.2
unnamed: Q14.3 (C), R38.2
unnamed: Q15.1 (B), R48.2
unnamed: Q15.3 (C), R39.2
unnamed: Q16.1 (B), R49.2
unnamed: Q16.3 (C), R40.2
unnamed: R1.2, U1.1
unnamed: R2.2, U2.1
unnamed: R3.2, U3.1
unnamed: R4.2, U4.1
unnamed: R21.2, U5.1
unnamed: R22.2, U6.1
unnamed: R23.2, U7.1
unnamed: R24.2, U8.1

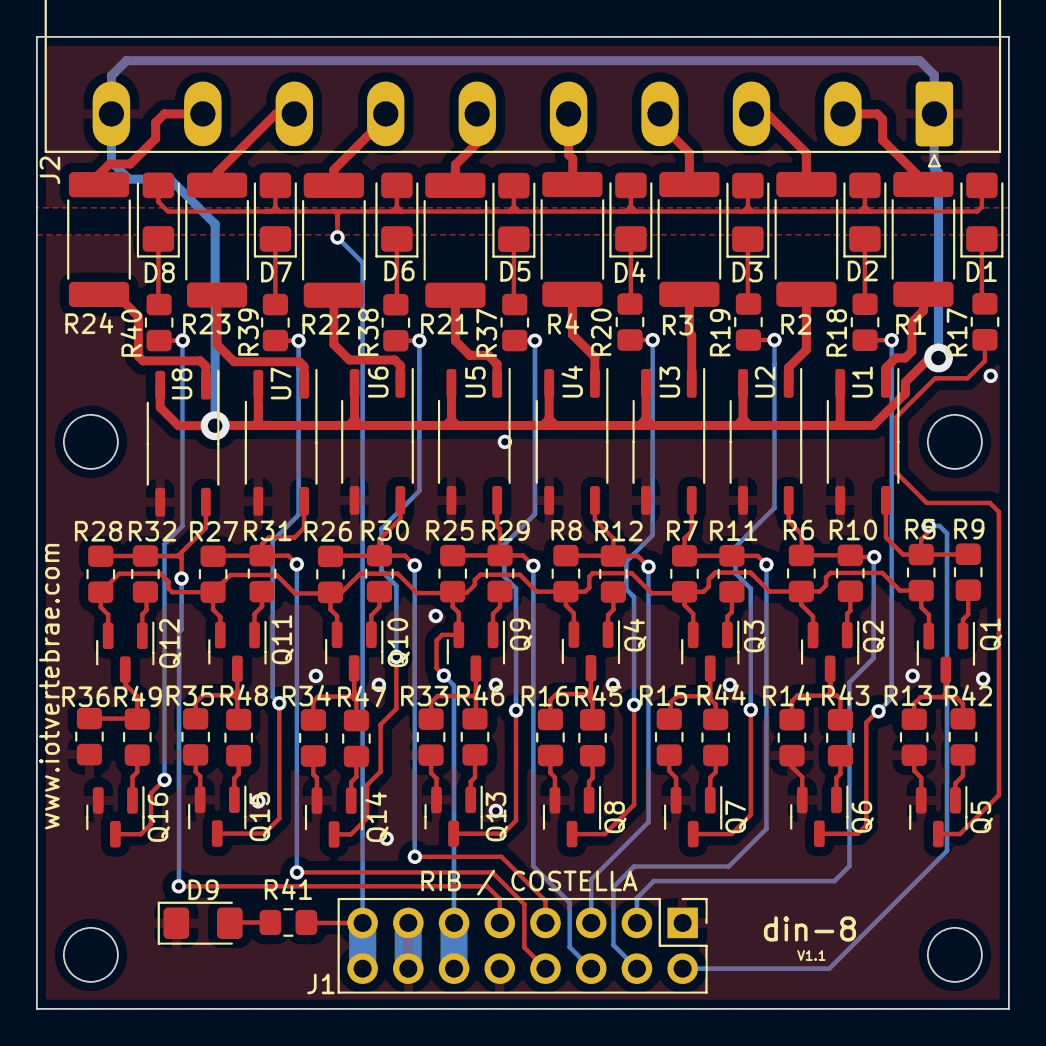
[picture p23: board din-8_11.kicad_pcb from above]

Board: 2 copper layers, 54.0 x 54.0 mm, 84 parts (0 on the bottom side), 69 nets.

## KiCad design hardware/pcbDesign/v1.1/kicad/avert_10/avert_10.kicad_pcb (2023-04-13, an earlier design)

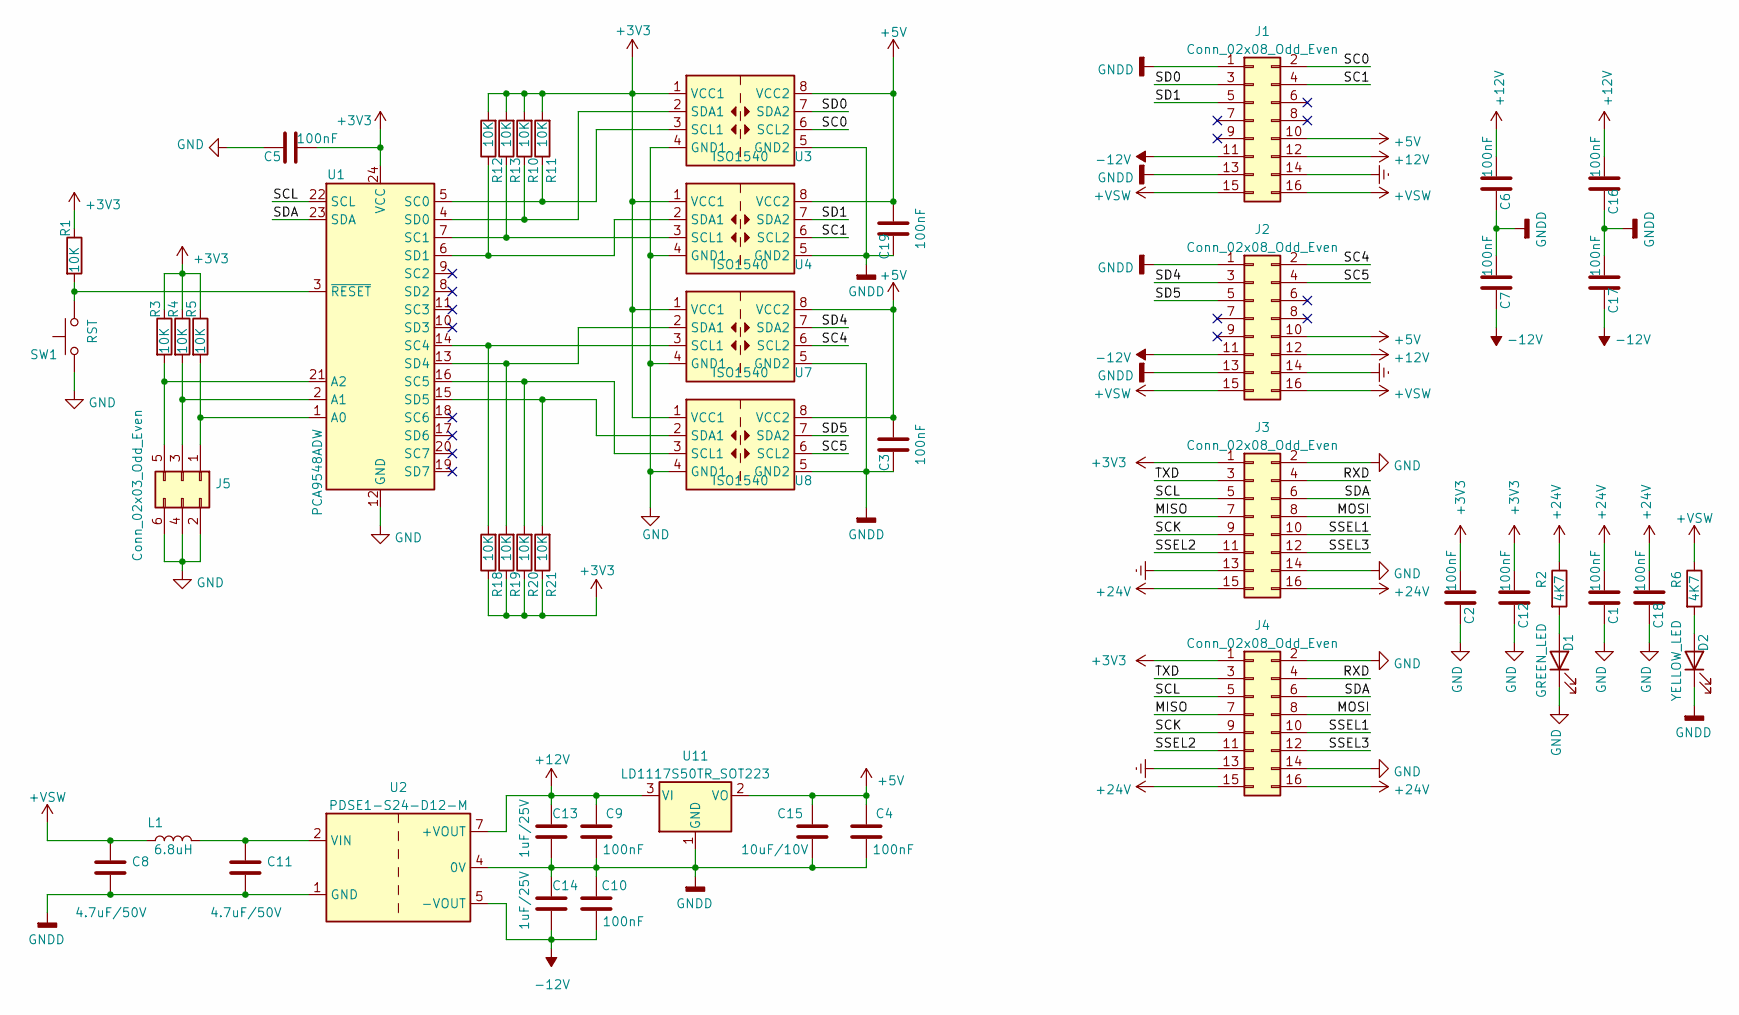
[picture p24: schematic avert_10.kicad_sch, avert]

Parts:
C1, C2, C3, C4, C5, C6, C7, C9, C10, C12, C16, C17, C18, C19: 100nF; C_0805_2012Metric_Pad1.18x1.45mm_HandSolder
C8, C11: 4.7uF/50V; C_0805_2012Metric_Pad1.18x1.45mm_HandSolder
C13, C14: 1uF/25V; C_0805_2012Metric_Pad1.18x1.45mm_HandSolder
C15: 10uF/10V; C_0805_2012Metric_Pad1.18x1.45mm_HandSolder
D1: GREEN_LED; LED_1206_3216Metric_Pad1.42x1.75mm_HandSolder
D2: YELLOW_LED; LED_1206_3216Metric_Pad1.42x1.75mm_HandSolder
J1, J2, J3, J4: Conn_02x08_Odd_Even; PinHeader_2x08_P2.54mm_Vertical
J5: Conn_02x03_Odd_Even; PinHeader_2x03_P2.54mm_Vertical
L1: 6.8uH; L_Bourns_SRP7028A_7.3x6.6mm
R1, R3, R4, R5, R10, R11, R12, R13, R18, R19, R20, R21: 10K; R_0805_2012Metric_Pad1.20x1.40mm_HandSolder
R2, R6: 4K7; R_0805_2012Metric_Pad1.20x1.40mm_HandSolder
SW1: RST; SW_SPST_CK_RS282G05A3
U1: PCA9548ADW; SOIC-24W_7.5x15.4mm_P1.27mm
U2: PDSE1-S24-D12-M; PDESE1-S24-D12-M
U3, U4, U7, U8: ISO1540; SOIC-8_3.9x4.9mm_P1.27mm
U11: LD1117S50TR_SOT223; SOT-223-3_TabPin2

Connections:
+3V3: C2.1, C5.1, C12.1, J3.1, J4.1, R1.1, R3.1, R4.1, R5.1, R10.2, R11.2, R12.2, R13.2, R18.1, R19.1, R20.1, R21.1, U1.24 (VCC), U3.1 (VCC1), U4.1 (VCC1), U7.1 (VCC1), U8.1 (VCC1)
+5V: C3.1, C4.1, C15.1, C19.1, J1.10, J2.10, U3.8 (VCC2), U4.8 (VCC2), U7.8 (VCC2), U8.8 (VCC2), U11.2 (VO)
+12V: C6.1, C9.1, C13.1, C16.1, J1.12, J2.12, U2.7 (+VOUT), U11.3 (VI)
+24V: C1.1, C18.1, J3.15, J3.16, J4.15, J4.16, R2.1
+VSW: C8.1, J1.15, J1.16, J2.15, J2.16, L1.1, R6.1
-12V: C7.2, C10.2, C14.2, C17.2, J1.11, J2.11, U2.5 (-VOUT)
/MISO: J3.7, J4.7
/MOSI: J3.8, J4.8
/RXD: J3.4, J4.4
/SC0: J1.2, U3.6 (SCL2)
/SC1: J1.4, U4.6 (SCL2)
/SC4: J2.2, U7.6 (SCL2)
/SC5: J2.4, U8.6 (SCL2)
/SCK: J3.9, J4.9
/SCL: J3.5, J4.5, U1.22 (SCL)
/SD0: J1.3, U3.7 (SDA2)
/SD1: J1.5, U4.7 (SDA2)
/SD4: J2.3, U7.7 (SDA2)
/SD5: J2.5, U8.7 (SDA2)
/SDA: J3.6, J4.6, U1.23 (SDA)
/SSEL1: J3.10, J4.10
/SSEL2: J3.11, J4.11
/SSEL3: J3.12, J4.12
/TXD: J3.3, J4.3
Earth: J1.14, J2.14, J3.13, J4.13
GND: C1.2, C2.2, C5.2, C12.2, C18.2, D1.1 (K), J3.2, J3.14, J4.2, J4.14, J5.2, J5.4, J5.6, SW1.1, U1.12 (GND), U3.4 (GND1), U4.4 (GND1), U7.4 (GND1), U8.4 (GND1)
GNDD: C3.2, C4.2, C6.2, C7.1, C8.2, C9.2, C10.1, C11.2, C13.2, C14.1, C15.2, C16.2, C17.1, C19.2, D2.1 (K), J1.1, J1.13, J2.1, J2.13, U2.1 (GND), U2.4 (0V), U3.5 (GND2), U4.5 (GND2), U7.5 (GND2), U8.5 (GND2), U11.1 (GND)
unnamed: C11.1, L1.2, U2.2 (VIN)
unnamed: D1.2 (A), R2.2
unnamed: D2.2 (A), R6.2
unnamed: J5.1, R5.2, U1.1 (A0)
unnamed: J5.3, R4.2, U1.2 (A1)
unnamed: J5.5, R3.2, U1.21 (A2)
unnamed: R1.2, SW1.2, U1.3 (~RESET)
unnamed: R10.1, U1.4 (SD0), U3.2 (SDA1)
unnamed: R11.1, U1.5 (SC0), U3.3 (SCL1)
unnamed: R12.1, U1.6 (SD1), U4.2 (SDA1)
unnamed: R13.1, U1.7 (SC1), U4.3 (SCL1)
unnamed: R18.2, U1.14 (SC4), U7.3 (SCL1)
unnamed: R19.2, U1.13 (SD4), U7.2 (SDA1)
unnamed: R20.2, U1.16 (SC5), U8.3 (SCL1)
unnamed: R21.2, U1.15 (SD5), U8.2 (SDA1)

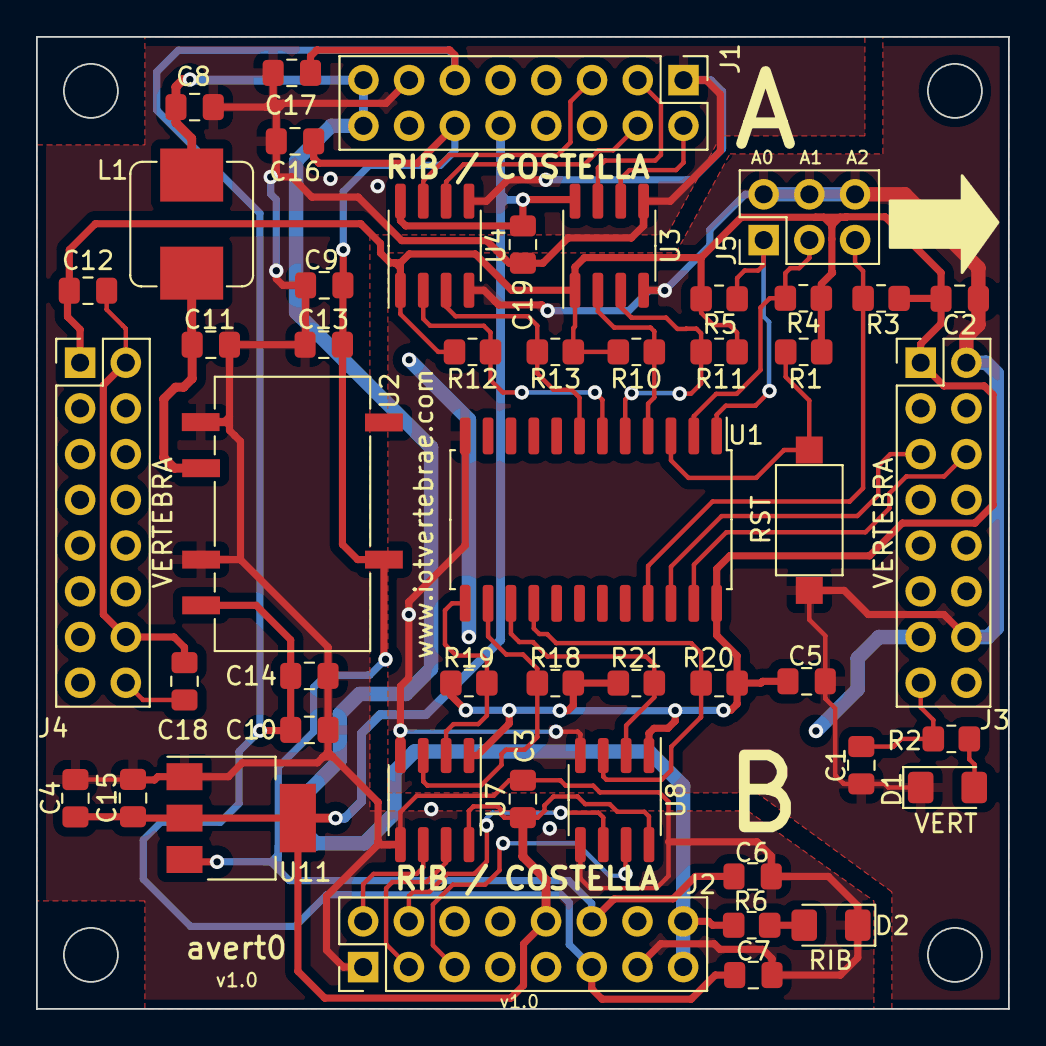
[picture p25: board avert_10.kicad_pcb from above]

Board: 4 copper layers, 54.0 x 54.0 mm, 49 parts (0 on the bottom side), 42 nets.

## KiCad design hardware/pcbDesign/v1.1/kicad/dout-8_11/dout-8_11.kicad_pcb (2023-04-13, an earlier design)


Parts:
D1: GREEN_LED; LED_1206_3216Metric_Pad1.42x1.75mm_HandSolder
D2, D3, D4, D5, D6, D7, D20, D21: RED_LED; LED_1206_3216Metric_Pad1.42x1.75mm_HandSolder
D8, D9, D10, D11, D12, D13, D14, D15, D16, D17, D18, D19, D22, D23, D24, D25: LL4148; D_MiniMELF
F1, F2, F3, F4, F5, F6, F7, F8: MF-USMF010-2; Fuse_1210_3225Metric_Pad1.42x2.65mm_HandSolder
J1: Conn_02x08_Odd_Even; PinHeader_2x08_P2.54mm_Vertical
J2: Conn_01x10; PhoenixContact_MSTBA_2,5_10-G-5,08_1x10_P5.08mm_Horizontal
J3: Conn_01x03; PinHeader_1x03_P2.54mm_Vertical
Q1, Q2, Q3, Q4, Q5, Q6, Q7, Q8: BC817; SOT-23
R1, R4, R5, R6, R7, R10, R11, R12, R13, R16, R17, R18, R19, R22, R23, R24, R25: 4K7; R_0805_2012Metric_Pad1.20x1.40mm_HandSolder
R2, R3, R8, R9, R14, R15, R20, R21: 1K; R_0805_2012Metric_Pad1.20x1.40mm_HandSolder
U1, U2, U3, U4, U5, U6, U7, U8: CPC1017N; SOP-4_3.8x4.1mm_P2.54mm

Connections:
+3.3V: J1.11, J1.12
+24V: J1.15, J1.16, R1.1, R4.1, R5.1, R6.1, R7.1, R10.1, R11.1, R12.1, R13.1, R16.1, R17.1, R18.1, R19.1, R22.1, R23.1, R24.1, R25.1
+VDC: D14.1 (K), D15.1 (K), D16.1 (K), D17.1 (K), D18.1 (K), D19.1 (K), D24.1 (K), D25.1 (K), J2.9, J3.3
/COM: J3.2, U1.3, U2.3, U3.3, U4.3, U5.3, U6.3, U7.3, U8.3
/O0: J1.2, R2.1
/O1: J1.3, R3.1
/O2: J1.4, R8.1
/O3: J1.5, R9.1
/O4: J1.6, R14.1
/O5: J1.7, R15.1
/O6: J1.8, R20.1
/O7: J1.9, R21.1
/OUT_0: D8.1 (K), D14.2 (A), F1.2, J2.1
/OUT_1: D9.1 (K), D15.2 (A), F2.2, J2.2
/OUT_2: D10.1 (K), D16.2 (A), F3.2, J2.3
/OUT_3: D11.1 (K), D17.2 (A), F4.2, J2.4
/OUT_4: D12.1 (K), D18.2 (A), F5.2, J2.5
/OUT_5: D13.1 (K), D19.2 (A), F6.2, J2.6
/OUT_6: D22.1 (K), D24.2 (A), F7.2, J2.7
/OUT_7: D23.1 (K), D25.2 (A), F8.2, J2.8
GND: D1.1 (K), J1.1, J1.10, J1.13, J1.14, Q1.2 (E), Q2.2 (E), Q3.2 (E), Q4.2 (E), Q5.2 (E), Q6.2 (E), Q7.2 (E), Q8.2 (E)
GNDD: D8.2 (A), D9.2 (A), D10.2 (A), D11.2 (A), D12.2 (A), D13.2 (A), D22.2 (A), D23.2 (A), J2.10, J3.1
unnamed: D1.2 (A), R1.2
unnamed: D2.1 (K), Q1.3 (C), U1.2
unnamed: D2.2 (A), R4.2
unnamed: D3.1 (K), Q2.3 (C), U2.2
unnamed: D3.2 (A), R5.2
unnamed: D4.1 (K), Q3.3 (C), U3.2
unnamed: D4.2 (A), R10.2
unnamed: D5.1 (K), Q4.3 (C), U4.2
unnamed: D5.2 (A), R11.2
unnamed: D6.1 (K), Q5.3 (C), U5.2
unnamed: D6.2 (A), R16.2
unnamed: D7.1 (K), Q6.3 (C), U6.2
unnamed: D7.2 (A), R17.2
unnamed: D20.1 (K), Q7.3 (C), U8.2
unnamed: D20.2 (A), R22.2
unnamed: D21.1 (K), Q8.3 (C), U7.2
unnamed: D21.2 (A), R23.2
unnamed: F1.1, U1.4
unnamed: F2.1, U2.4
unnamed: F3.1, U3.4
unnamed: F4.1, U4.4
unnamed: F5.1, U5.4
unnamed: F6.1, U6.4
unnamed: F7.1, U8.4
unnamed: F8.1, U7.4
unnamed: Q1.1 (B), R2.2
unnamed: Q2.1 (B), R3.2
unnamed: Q3.1 (B), R8.2
unnamed: Q4.1 (B), R9.2
unnamed: Q5.1 (B), R14.2
unnamed: Q6.1 (B), R15.2
unnamed: Q7.1 (B), R20.2
unnamed: Q8.1 (B), R21.2
unnamed: R6.2, U1.1
unnamed: R7.2, U2.1
unnamed: R12.2, U3.1
unnamed: R13.2, U4.1
unnamed: R18.2, U5.1
unnamed: R19.2, U6.1
unnamed: R24.2, U8.1
unnamed: R25.2, U7.1

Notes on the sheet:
COMMON SELECTOR
CFG NPN:
COM AT
CFG PNP:


Board: 2 copper layers, 54.0 x 54.0 mm, 77 parts (0 on the bottom side), 63 nets.

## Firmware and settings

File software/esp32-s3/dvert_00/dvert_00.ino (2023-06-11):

/*

* Register:
b7 b6 b5 b4 b3 b2 b1 b0
x  x  x  x  x  0  0  0     REG_CFG
x  x  x  x  x  0  0  1     REG_RD
x  x  x  x  x  0  1  0     REG_WR
x  x  x  x  x  0  1  1     REG_PWM
x  x  x  x  x  1  0  0     CFG_PWM
x  x  x  x  x  1  0  1     RD_CFG
x  x  x  x  x  1  1  0     VERT_VERS

b3: 0 <-- byte
b3: 1 <-- bit

b4: 0 <-- A rib
b4: 1 <-- B rib

b7 b6 b5 : bit port address (if b3 == 1)

** Register REG_CFG:
b7 b6 b5 b4 b3 b2 b1 b0
x  x  x  x  x  0  0  0     REG_CFG

i2cset -y 1 <I2C addr byte> <REG byte> <COMMAND word> w
0: Output
1: Input
00: 8 outputs
FF: 8 inputs

A output, B input:
i2cset -y 1 0x20 0x00 0x00FF w

A and B inputs:
i2cset -y 1 0x20 0x00 0xFFFF w

A input and B output:
i2cset -y 1 0x20 0x00 0xFF00 w

A and B outputs:
i2cset -y 1 0x20 0x00 0x0000 w

** Register REG_WR:
b7 b6 b5 b4 b3 b2 b1 b0
x  x  x  x  x  0  1  0     REG_WR

Writing bit or byte:
b3 (REG_WR): 0 <-- byte
b3 (REG_WR): 1 <-- bit

A or B rib:
b4 (REG_WR): 0 <-- A rib
b4 (REG_WR): 1 <-- B rib

Which bit (0..7):
b7 b6 b5 b4 b3 b2 b1 b0
0  0  0  x  1  0  1  0     bit 0
0  0  1  x  1  0  1  0     bit 1
0  1  0  x  1  0  1  0     bit 2
0  1  1  x  1  0  1  0     bit 3
1  0  0  x  1  0  1  0     bit 4
1  0  1  x  1  0  1  0     bit 5
1  1  0  x  1  0  1  0     bit 6
1  1  1  x  1  0  1  0     bit 7

Sending 1 (0x01) to 0x20 vertebra / A rib / bit Output 0 
i2cset -y 1 0x20 0x0a 0x01
Reg 0x0a:
b7 b6 b5 b4 b3 b2 b1 b0
0  0  0  0  1  0  1  0

Sending 0 (0x00) to 0x20 vertebra / A rib / bit Output 0 
i2cset -y 1 0x20 0x0a 0x00

Sending 1 (0x01) to 0x20 vertebra / B rib / bit Output 0 
i2cset -y 1 0x20 0x1a 0x01
Reg 0x1a:
b7 b6 b5 b4 b3 b2 b1 b0
0  0  0  1  1  0  1  0

Sending 0 (0x00) to 0x20 vertebra / B rib / bit Output 0 
i2cset -y 1 0x20 0x1a 0x00

Sending 01011010 (0x5a) to 0x20 vertebra / A rib  
i2cset -y 1 0x20 0x02 0x5a

Sending 10110101 (0xa5) to 0x20 vertebra / A rib  
i2cset -y 1 0x20 0x02 0xa5

Sending 00001111 (0x0f) to 0x20 vertebra / B rib  
i2cset -y 1 0x20 0x12 0x0f

Sending 11110000 (0xf0) to 0x20 vertebra / B rib  
i2cset -y 1 0x20 0x12 0x0f

Sending 11110000 (0xf0) to 0x20 vertebra / A rib  
i2cset -y 1 0x20 0x02 0x0f

** Register REG_RD:
* b7 b6 b5 b4 b3 b2 b1 b0
x  x  x  x  x  0  0  1     REG_RD

b4: 0 <-- A rib
b4: 1 <-- B rib

Raspberry Pi needs two I2C sendings to read properly.

Reading A rib / 0x20 vertebra
i2cget -y 1 0x20 0x01
i2cget -y 1 0x20 0x01

Reading B rib / 0x20 vertebra
i2cget -y 1 0x20 0x11
i2cget -y 1 0x20 0x11

** Register CFG_PWM:
b7 b6 b5 b4 b3 b2 b1 b0
x  x  x  x  x  1  0  0     CFG_PWM

This digital vertebra is using an ESP32-S3.
ESP32 has 16 PWM channels, ESP32-C3 has 6 PWM channels.
ESP32-S2 and ESP32-S3 have 8 PWM channels.

Only one register ( A rib or B rib ) can be PWM at the same time.

A rib (0x00) as 8 PWM outputs:
i2cset -y 1 0x20 0x04 0x00

B rib (0x01) as 8 PWM outputs:
i2cset -y 1 0x20 0x04 0x01


** Register REG_PWM:
b7 b6 b5 b4 b3 b2 b1 b0
x  x  x  x  x  0  1  1     REG_PWM

Sending 200 (range from 0 to 255) to B rib (b4 = 1) to bit (b3 = 1) 2 (b7=0, b6=1, b5 = 0) at 0x20 vertebra
i2cset -y 1 0x20 0x5B 200
b7 b6 b5 b4 b3 b2 b1 b0
0  1  0  1  1  0  1  1     REG_PWM

Sending 5 (range from 0 to 255) to B rib (b4 = 1) to 8 outputs (b3 = 0) at 0x20 vertebra
i2cset -y 1 0x20 0x13 5
b7 b6 b5 b4 b3 b2 b1 b0
0  0  0  1  0  0  1  1     REG_PWM

** Register RD_CFG:
b7 b6 b5 b4 b3 b2 b1 b0
x  x  x  x  x  1  0  1     RD_CFG

Raspberry Pi needs two I2C sendings to read properly.
i2cget -y 1 0x20 0x05
i2cget -y 1 0x20 0x05

Answer
0  x  x  x  0  0  0  1     A input
0  0  0  1  0  x  x  x     B input
0  x  x  x  0  0  1  0     A output
0  0  1  0  0  x  x  x     B output
0  x  x  x  0  1  0  0     A pwm
0  1  0  0  0  x  x  x     B pwm

** Register VERSION:
b7 b6 b5 b4 b3 b2 b1 b0
x  x  x  x  x  1  1  0     VERT_VERS

Raspberry Pi needs two I2C sendings to read properly.
i2cget -y 1 0x20 0x06 w
i2cget -y 1 0x20 0x06 w


Jordi Binefa - 20230602
iotvertebrae.com
 */
#include <Wire.h>

#define I2C_ADDR_BASE 0x20

#define DVERT_VERSION    0x01
#define DVERT_SUBVERSION 0x00

#define ADDR0 20
#define ADDR1 19
#define ADDR2 16
#define ADDR3 15
#define LED_MQTT 48
#define A0 14
#define A1 21
#define A2 39
#define A3 40
#define A4 41
#define A5 42
#define A6 2
#define A7 1
#define B0 4
#define B1 5
#define B2 6
#define B3 7
#define B4 13
#define B5 12
#define B6 11
#define B7 10

#define REG_CFG   0x00
#define REG_RD    0x01
#define REG_WR    0x02
#define REG_PWM   0x03
#define CFG_PWM   0x04
#define RD_CFG    0x05
#define VERT_VERS 0x06

const byte cbA[8] = {A0,A1,A2,A3,A4,A5,A6,A7};
const byte cbB[8] = {B0,B1,B2,B3,B4,B5,B6,B7};
byte byI2cAddr;
byte byLastReadNumber,byRibCfg;

void vSetupAddr(){
  pinMode(LED_MQTT, OUTPUT);
  pinMode(ADDR0, INPUT_PULLUP);
  pinMode(ADDR1, INPUT_PULLUP);
  pinMode(ADDR2, INPUT_PULLUP);
  pinMode(ADDR3, INPUT_PULLUP); 
}

void vSetupIO(String sQ,int nMode){
  int i;
  
  if(sQ == "A"){
    byRibCfg &= 0xF0;
    byRibCfg |= (nMode == INPUT)?0x01:0x02;
    for(i = 0; i < 8; i++)
      pinMode(cbA[i],nMode);
  }
  if(sQ == "B"){
    byRibCfg &= 0x0F;
    byRibCfg |= (nMode == INPUT)?0x10:0x20;
    for(i = 0; i < 8; i++)
      pinMode(cbB[i],nMode);
  }
}

void vSetupGPIO(word wCfg){
  word wI = 0x0001;
  int i;

  // Serial.print("Word: 0x");
  Serial.println(wCfg,HEX);

  for(i = 0; i < 8; i++,wI<<=1){
    pinMode(cbB[i],(wCfg & wI)?INPUT:OUTPUT);
    // Serial.print("cbB[");
    // Serial.print(i);
    // Serial.print("]: ");
    // Serial.println((wCfg & wI)?"INPUT":"OUTPUT");
    byRibCfg &= 0x0F; // It has sense when B rib are 8 inputs or 8 outputs
    byRibCfg |= (wCfg & wI)?0x10:0x20; // It has sense when B rib are 8 inputs or 8 outputs
  }
  for(i = 0; i < 8; i++,wI<<=1){
    pinMode(cbA[i],(wCfg & wI)?INPUT:OUTPUT);
    // Serial.print("cbA[");
    // Serial.print(i);
    // Serial.print("]: ");
    // Serial.println((wCfg & wI)?"INPUT":"OUTPUT");
    byRibCfg &= 0xF0; // It has sense when A rib are 8 inputs or 8 outputs
    byRibCfg |= (wCfg & wI)?0x01:0x02; // It has sense when A rib are 8 inputs or 8 outputs
  }  
}

void vSetupPWM(byte by){
  const int pwmFreq = 500,pwmResolution = 8;
  int i;
  
  if(by == 0x00){ // A port as PWM
    byRibCfg &= 0xF0;
    byRibCfg |= 0x04;
    for(i = 0; i < 8; i++){
      ledcSetup(i,pwmFreq,pwmResolution); // i: channel (0..15)
      ledcAttachPin(cbA[i], i);
      Serial.print("cbA[");
      Serial.print(i);
      Serial.print("] attached to ");
      Serial.print(i);
      Serial.println(" pwm channel");
    }
  }else{ // B port as PWM
    byRibCfg &= 0x0F;
    byRibCfg |= 0x40;
    for(i = 0; i < 8; i++){
      // ledcSetup(i+8,pwmFreq,pwmResolution); // i: channel (0..15)
      // ledcAttachPin(cbB[i], i+8);
      ledcSetup(i,pwmFreq,pwmResolution); // i: channel (0..7)
      ledcAttachPin(cbB[i], i);
      Serial.print("cbB[");
      Serial.print(i);
      Serial.print("] attached to ");
      // Serial.print(i+8);
      Serial.print(i);
      Serial.println(" pwm channel");
    }
  }
}

byte byReadI2cAddress(){
  byte byAddr = (digitalRead(ADDR3))?0x00:0x1;
  
  byAddr |= (digitalRead(ADDR2))?0x00:0x2;
  byAddr |= (digitalRead(ADDR1))?0x00:0x4;
  byAddr |= (digitalRead(ADDR0))?0x00:0x8;
  
  return I2C_ADDR_BASE | byAddr;
}

void vWrite(String sQ,byte by){
  byte byI = 0x01;
  int i;

  Serial.print("vWrite(");
  Serial.print(by,HEX);
  Serial.println("){");
  for(i = 0; i < 8; i++,byI<<=1){
    //Serial.print("GPIO: ");
    //Serial.print((sQ == "A")?cbA[i]:cbB[i]);
    //Serial.print(", Value: ");
    //Serial.println((by&byI)?HIGH:LOW);
    digitalWrite((sQ == "A")?cbA[i]:cbB[i],by&byI);
  }
  Serial.println(sQ);
  Serial.println("}vWrite");
}

byte byRead(String sQ){
  byte byI = 0x01,byR = 0x00;
  int i;

  for(i = 0; i < 8; i++,byI<<=1){
    byR |= (digitalRead((sQ == "A")?cbA[i]:cbB[i]))?byI:0x00;
    /* Serial.print((sQ == "A")?"a[":"b[");
    Serial.print(i);
    Serial.print("]: ");
    Serial.print(digitalRead((sQ == "A")?cbA[i]:cbB[i]));
    Serial.print(" - byI: ");
    Serial.print(byI,HEX);
    Serial.print(" - byR: ");
    Serial.println(byR,HEX); */
  }
  
  return byR; 
}

void requestEvent() {
  delay(100);
  if((byLastReadNumber & 0x07) == REG_RD){
        if(byLastReadNumber & 0x10){
          // Wire.write(0xB);
          Wire.write(byRead("B"));
        }else{
          // Wire.write(0xA);
          Wire.write(byRead("A"));
        }
  }
  if((byLastReadNumber & 0x7) == RD_CFG){
    Wire.write(byRibCfg);
  }
  if((byLastReadNumber & 0x7) == VERT_VERS){
        Wire.write(DVERT_SUBVERSION);
        Wire.write(DVERT_VERSION);
  }
}

void setup() {
  Serial.begin(115200);
  Serial.println(__FILE__);
  
  vSetupAddr();
  byI2cAddr = byReadI2cAddress();
  Serial.print("I2C address: 0x");
  Serial.println(byI2cAddr,HEX);

  Wire.begin(byI2cAddr);
  Wire.onReceive(BlinkLED);
  Wire.onRequest(requestEvent);

  byRibCfg = 0x00;
  vSetupIO("A",OUTPUT);
  vSetupIO("B",OUTPUT);
}

void BlinkLED(int Press) {
  enum {cfg,rd,wr,pwm,cfgPwm,rdCfg,versio,no} enReg = no;
  int n = 0,nPwmChannel,nBit,i;
  byte byCfgA,byCfgB,byReg;

  digitalWrite(LED_MQTT,HIGH);
  while (1 < Wire.available()) { // loop through all but the last
    byLastReadNumber = Wire.read();   // receive byte as a character
    Serial.print(n,DEC);
    Serial.print(") El màster m'ha fet arribar un 0x");
    Serial.println(byLastReadNumber,HEX);
    switch(n++){
      case 0:
        Serial.print("byLastReadNumber & 0x07: 0x");
        Serial.println(byLastReadNumber & 0x07,HEX);
        switch(byLastReadNumber & 0x07){
          case REG_CFG: enReg = cfg; break;
          case REG_RD:  enReg = rd; break;
          case REG_WR:  enReg = wr; break;
          case REG_PWM: enReg = pwm; break;
          case CFG_PWM: enReg = cfgPwm; /*Serial.println("enReg = cfgPwm")*/;break;
          case RD_CFG: enReg = rdCfg; Serial.println("enReg = rdCfg");break;
          case VERT_VERS: enReg = versio; Serial.println("enReg = versio");break;
          default: enReg = no; Serial.println("enReg = no");
        }
        byReg = byLastReadNumber;
        break;
      case 1:
        switch(enReg){
          case cfg:
            // Serial.print("Configuració B: 0x");
            // Serial.println(byLastReadNumber,HEX);
            byCfgB = byLastReadNumber;
            break;
        }
        break;
    }
  }
  byLastReadNumber = Wire.read();
  Serial.print(n,DEC);
  Serial.print("> El màster m'ha fet arribar un 0x");
  Serial.println(byLastReadNumber,HEX);
  switch(n){
    case 0:
      byReg = byLastReadNumber;
      if((byReg & 0x7) == REG_RD){
        Serial.print("byReg: 0x");
        Serial.println(byReg,HEX);
        Serial.println((byReg & 0x10)?"Sol·licitud de lectura B":"Sol·licitud de lectura A");
        /*if(byReg & 0x10){
          Wire.write(0xB);
        }else{
          Wire.write(0xA);
        }*/
      }   
      if((byReg & 0x7) == RD_CFG){
        Serial.println("Reading rib configuration");
      }
      if((byReg & 0x7) == VERT_VERS){
        Serial.println("Reading version");
        Wire.write(DVERT_VERSION);
        Wire.write(DVERT_SUBVERSION);
      }
      break;
    case 1:
      switch(enReg){
          case wr:
            if(byReg & 0x08){
              // Escriptura a nivell de bit
              Serial.print("bit: ");
              Serial.println(byReg >> 5);
              digitalWrite((byReg & 0x10)?cbB[byReg >> 5]:cbA[byReg >> 5],byLastReadNumber);
            }else{
              // Escriptura a nivell de byte
              // Serial.println(byReg,HEX);
              vWrite((byReg & 0x10)?"B":"A",byLastReadNumber);
            }
            break;        
           case pwm:
            Serial.print("PWM byReg: 0x");
            Serial.println(byReg,HEX);
            if(byReg & 0x08){
              // Escriptura a nivell de bit
              Serial.print("PWM ");
              Serial.print((byReg & 0x10)?"b[":"a[");
              nBit = byReg >> 5;
              Serial.print(nBit);
              Serial.print("]: ");
              Serial.println(byLastReadNumber,DEC);
              // nPwmChannel = nBit + ((byReg & 0x10)?8:0);
              nPwmChannel = nBit;
              Serial.print("PWM channel: ");
              Serial.println(nPwmChannel,DEC);
              ledcWrite(nPwmChannel,byLastReadNumber);
            }else{
              // Escriptura a nivell de byte
              // Serial.println(byReg,HEX);
              Serial.print("PWM ");
              Serial.print((byReg & 0x10)?"B: ":"A: ");
              Serial.println(byLastReadNumber,DEC);             
              Serial.print("PWM channels: ");
              //Serial.println((byReg & 0x10)?"All from 8 to 15":"All from 0 to 7");
              Serial.println("All from 0 to 7");
              for(i = 0; i < 8 ; i++){
                ledcWrite(i,byLastReadNumber);
              }
            }
            break;
           case cfgPwm:
            Serial.print("CFG PWM: ");
            Serial.println(byLastReadNumber,DEC);
            vSetupPWM(byLastReadNumber); // A: 0x00, B: 0x01
            break;        
     }
      break;
   
    case 2:
      switch(enReg){
          case cfg:
            // Serial.print("Configuració A: 0x");
            // Serial.println(byLastReadNumber,HEX);
            byCfgA = byLastReadNumber;
            vSetupGPIO(byCfgA << 8 | byCfgB);
            break;
      }
      break;
    default:
      switch(enReg){
          case cfg:
            Serial.println("I don't understand your port setup.");
      }    
  }
  digitalWrite(LED_MQTT,LOW);
}
/*
void requestEvent() {
  Serial.print("Esclau respon 0x");
  Serial.print(byLastReadNumber%2,HEX);
  Serial.print(" 0x");
  Serial.println(byLastReadNumber+5,HEX);
  Wire.write(byLastReadNumber%2); // respond with message of 1 byte
  Wire.write(byLastReadNumber+5); // respond with message of 1 byte
  // Wire.endTransmission(); // No millora el decalatge
  // as expected by master
  Serial.println((byLastReadNumber & 0x10)?"B":"A");
}*/

void loop() {
  delay(100);
}

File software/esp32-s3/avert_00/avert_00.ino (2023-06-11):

/*
Testing:

Sending 0 volts DAC V04:
iot@iot-vertebrae:~ $ i2cset -y 1 0x10 0x72 0x0000 w

Reading ADC A4
iot@iot-vertebrae:~ $ i2cget -y 1 0x10 0x61 w
0x2121
iot@iot-vertebrae:~ $ i2cget -y 1 0x10 0x61 w
0x33f0

Sending 10 volts DAC V04 (0x0FFF or 4095):
iot@iot-vertebrae:~ $ i2cset -y 1 0x10 0x72 0xff0f w

Reading ADC A4
iot@iot-vertebrae:~ $ i2cget -y 1 0x10 0x61 w
0x2121
iot@iot-vertebrae:~ $ i2cget -y 1 0x10 0x61 w
0x67a0
iot@iot-vertebrae:~ $
----
Sending 10 volts DAC V03:
iot@iot-vertebrae:~ $ i2cset -y 1 0x10 0x52 0xff0f w

Reading ADC A3:
iot@iot-vertebrae:~ $ i2cget -y 1 0x10 0x41 w
0x2121
iot@iot-vertebrae:~ $ i2cget -y 1 0x10 0x41 w
0x6720

Sending 10 volts DAC V03:
iot@iot-vertebrae:~ $ i2cset -y 1 0x10 0x52 0x0000 w

Reading ADC A3:
iot@iot-vertebrae:~ $ i2cget -y 1 0x10 0x41 w
0x2121
iot@iot-vertebrae:~ $ i2cget -y 1 0x10 0x41 w
0x33a0
iot@iot-vertebrae:~ $ 
----
Sending 10 volts DAC V02:
iot@iot-vertebrae:~ $ i2cset -y 1 0x10 0x32 0xff0f w

Reading ADC A2:
iot@iot-vertebrae:~ $ i2cget -y 1 0x10 0x21 w
0x2121
iot@iot-vertebrae:~ $ i2cget -y 1 0x10 0x21 w
0x6770

Sending 0 volts DAC V02:
iot@iot-vertebrae:~ $ i2cset -y 1 0x10 0x32 0x0000 w

Reading ADC A2:
iot@iot-vertebrae:~ $ i2cget -y 1 0x10 0x21 w
0x2121
iot@iot-vertebrae:~ $ i2cget -y 1 0x10 0x21 w
0x33e0
iot@iot-vertebrae:~ $
----
Sending 10 volts DAC V01:
iot@iot-vertebrae:~ $ i2cset -y 1 0x10 0x12 0xff0f w

Reading ADC A1:
iot@iot-vertebrae:~ $ i2cget -y 1 0x10 0x01 w
0x2121
iot@iot-vertebrae:~ $ i2cget -y 1 0x10 0x01 w
0x6780

Sending 0 volts DAC V01:
iot@iot-vertebrae:~ $ i2cset -y 1 0x10 0x12 0x0000 w

Reading ADC A1:
iot@iot-vertebrae:~ $ i2cget -y 1 0x10 0x01 w
0x2121
iot@iot-vertebrae:~ $ i2cget -y 1 0x10 0x01 w
0x33e0
iot@iot-vertebrae:~ $
----

* Register:
b7 b6 b5 b4 b3 b2 b1 b0
0  x  x  x  0  0  0  1     REG_RD
0  x  x  x  0  0  1  0     REG_WR
0  0  x  x  0  1  0  1     RD_CFG
0  0  0  0  0  1  1  0     VERT_VERS
0  0  0  0  0  1  1  1     CHECK

b4: 0 <-- A rib
b4: 1 <-- B rib

b6 b5 : port address (0..3)

** Register REG_RD:
b7 b6 b5 b4 b3 b2 b1 b0
0  x  x  x  0  0  0  1     REG_RD

Reading ADC's channel 0, A rib
i2cget -y 1 0x10 0x01 w

Reading ADC's channel 1, A rib
i2cget -y 1 0x10 0x21 w

Reading ADC's channel 2, A rib
i2cget -y 1 0x10 0x41 w

Reading ADC's channel 3, A rib
i2cget -y 1 0x10 0x61 w

** Register REG_WR:
* 
b7 b6 b5 b4 b3 b2 b1 b0
0  x  x  x  0  0  1  0     REG_WR

Sending 1 (0..4095) to 0 channel A rib
i2cset -y 1 0x10 0x02 0x0100 w

Sending 256 (0..4095) to 0 channel B rib
i2cset -y 1 0x10 0x12 0x0001 w

Sending 4095 (0..4095) to 3 channel A rib
i2cset -y 1 0x10 0x62 0xff0f w

** Register RD_CFG:
b7 b6 b5 b4 b3 b2 b1 b0
0  0  x  x  0  1  0  1     RD_CFG

b5: 0 <-- Read ribs configuration (2 bytes)
b5: 1 <-- Read A or B rib configuration (1 byte)

b4: 0 <-- A rib
b4: 1 <-- B rib

Raspberry Pi needs two I2C sendings to read properly.

A rib configuration (b5: 1, b4: 0):
i2cget -y 1 0x10 0x25
i2cget -y 1 0x10 0x25
0x01

B rib configuration (b5: 1, b4: 1):
i2cget -y 1 0x10 0x35
i2cget -y 1 0x10 0x35
0x02

0  0  0  0  0  0  0  0  (0x00) Rib is not connected or rib type is unknown.
0  0  0  0  0  0  0  1  (0x01) Rib is ADC
0  0  0  0  0  0  1  0  (0x02) Rib is DAC

Both ribs configuration (b5: 0, b4: x):
i2cget -y 1 0x10 0x05 w
i2cget -y 1 0x10 0x05 w
0x0201

Answer
x  x  x  x  x  x  x  x  0  0  0  0  0  0  0  0  A rib is not connected or rib type is unknown.
0  0  0  0  0  0  0  0  x  x  x  x  x  x  x  x  B rib is not connected or rib type is unknown.
x  x  x  x  x  x  x  x  0  0  0  0  0  0  0  1  A rib is ADC
0  0  0  0  0  0  0  1  x  x  x  x  x  x  x  x  B rib is ADC
x  x  x  x  x  x  x  x  0  0  0  0  0  0  1  0  A rib is DAC
0  0  0  0  0  0  1  0  x  x  x  x  x  x  x  x  B rib is DAC

0x0201: B rib is DAC (0x02) and A rib is ADC (0x01)

** Register VERSION:
b7 b6 b5 b4 b3 b2 b1 b0
x  x  x  x  x  1  1  0     VERT_VERS

Raspberry Pi needs two I2C sendings to read properly.
i2cget -y 1 0x10 0x06 w
i2cget -y 1 0x10 0x06 w
0x0100

Answer 0x0100:
01: VERSION
00: SUBVERSION

** Register CHECK:
b7 b6 b5 b4 b3 b2 b1 b0
x  x  x  x  x  1  1  1     CHECK

i2cset -y 1 0x10 0x07

Jordi Binefa - 20230605
iotvertebrae.com
*/

#include <Wire.h>

#define I2C_ADDR_BASE 0x10

#define DVERT_VERSION    0x01
#define DVERT_SUBVERSION 0x00

#define ADDR0 20
#define ADDR1 19
#define ADDR2 16
#define ADDR3 15
#define LED_MQTT 48

#define SCL0 14
#define SDA0 21
#define SCL1  1
#define SDA1  2
#define SCL2  7
#define SDA2  6
#define SCL3  5
#define SDA3  4

#define CTX  17
#define CRX  18

#define TYPE_NONE 0x00
#define TYPE_ADC  0x01
#define TYPE_DAC  0x02

// #define REG_CFG   0x00
#define REG_RD    0x01
#define REG_WR    0x02
// #define REG_PWM   0x03
// #define CFG_PWM   0x04
#define RD_CFG    0x05
#define VERT_VERS 0x06
#define CHECK 0x07

#define MINIMUM_DELAY_ALLOWING_MULTITASKING 50

#define FUNC_vReadAdc             1
#define FUNC_vWriteDac            2
#define FUNC_vCheckI2C            3
#define FUNC_vManageReadRibTypes  4

TaskHandle_t TaskSlave;
TaskHandle_t TaskMaster;

uint32_t i = 0;
  
TwoWire I2C_M = TwoWire(0); // Main I2C. ESP32-S3 acting as slave
TwoWire I2C_S = TwoWire(1); // Slaves I2C. ESP32-S3 acting as master

const byte cbSDA_S[4] = {SDA0,SDA1,SDA2,SDA3};
const byte cbSCL_S[4] = {SCL0,SCL1,SCL2,SCL3};

byte byLastReadNumber,byRibA,byRibB;

static SemaphoreHandle_t mutex;
static const uint8_t nMsgQueueLen = 255;
static const uint8_t nTicksTryingAddItemToQueue = 10;
static QueueHandle_t qMsgQueue;

struct stI2C{
  int nFunc;
  byte byReg;
  short int siValue;
};

struct stAdcRibs{
  word wArib[4];
  word wBrib[4];
}stADC;

bool bIO0pressed(){
  return !digitalRead(0);
}

void vSetupAddr(){
  pinMode(LED_MQTT, OUTPUT);
  pinMode(ADDR0, INPUT_PULLUP);
  pinMode(ADDR1, INPUT_PULLUP);
  pinMode(ADDR2, INPUT_PULLUP);
  pinMode(ADDR3, INPUT_PULLUP); 
}

byte byReadI2cAddress(){
  byte byAddr = (digitalRead(ADDR3))?0x00:0x1;
  
  byAddr |= (digitalRead(ADDR2))?0x00:0x2;
  byAddr |= (digitalRead(ADDR1))?0x00:0x4;
  byAddr |= (digitalRead(ADDR0))?0x00:0x8;
  
  return I2C_ADDR_BASE | byAddr;
}

void vDiscoverI2cDevices(TwoWire *i2c,int whichOne){
  byte error, address;
  int nDevices;
  
  Serial.print("Scanning I2C");
  Serial.print(whichOne,DEC);
  Serial.println(":");
  nDevices = 0;
  for(address = 1; address < 127; address++ ) {
    i2c->beginTransmission(address);
    error = i2c->endTransmission();
    if (error == 0) {
      Serial.print("I2C device found at address 0x");
      if (address<16) {
        Serial.print("0");
      }
      Serial.println(address,HEX);
      nDevices++;
    }
    else if (error==4) {
      Serial.print("Unknow error at address 0x");
      if (address<16) {
        Serial.print("0");
      }
      Serial.println(address,HEX);
    }    
  }
  if (nDevices == 0) {
    Serial.println("No I2C devices found\n");
  }
  else {
    Serial.println("done\n");
  }
  Serial.println("---------------------------"); 
}
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
